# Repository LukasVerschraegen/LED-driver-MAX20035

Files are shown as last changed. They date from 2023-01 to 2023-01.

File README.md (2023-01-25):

# LED-driver-MAX20035
Dit is een schoolproject voor de vakken Industriële toepassing (vermogenelektronica) en Geavanceerd printontwerp.

Enkele video's zijn terug te vinden op mijn youtube kanaal.
https://www.youtube.com/watch?v=1G2xKRNUYQ0&list=PL1lBQKZjCus0v_I9x_oXpihpboHuMBEch




[omschrijving project.pdf](https://github.com/LukasVerschraegen/LED-driver-MAX20035/files/10492971/omschrijving.project.pdf)

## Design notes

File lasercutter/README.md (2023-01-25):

De DXF file is een file dat de lasercutter verstaat om een deksel te maken voor het ontwerp, voor elk materiaal dat u wilt gebruiken zijn er speciefieke instellingen.
Check daarvoor de fabrikant zijn aanradingen en maak dan nodige aanpassingen.

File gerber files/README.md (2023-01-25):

Als u dit ontwerp zelf wilt maken, gaat u naar een fabrikant en dient u deze files in onder de vorm van een 4 layer pcb.

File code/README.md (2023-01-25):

Ik heb een code geschreven voor pwm dimming.
Met de 2de code kan je met je gsm het pwm percentage aanpassen.

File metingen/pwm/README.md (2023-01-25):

Dit is een pwm meting bij 10% pwm, dit varieert constant aangezien we een zwaailicht hebben gemaakt.

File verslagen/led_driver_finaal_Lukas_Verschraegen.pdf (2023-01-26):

Academiejaar: 2022 / 2023

# Led driver project

Verslaggever: | Lukas Verschraegen
Klas: | 3ELO
Lector: | Piet Coussens / Dirk Claus

## Inhoudstafel:

Er zijn ook twee linken die alles in het project omschrijven:
- Er is een link naar een Github pagina, waar elke file ter beschikking is.
- https://github.com/LukasVerschraegen/LED-driver-MAX20035
- Er is een link naar een Youtube pagina waar alle testen te zien zijn.
- https://www.youtube.com/watch?v=1G2xKRNUYQ0&list=PL1lBQKZjCus0v_I9x_oXpi hpboHuMBEch (https://www.youtube.com/watch?v=1G2xKRNUYQ0&list=PL1lBQKZjCus0v_I9x_oXpihpboHuMBEch)

## 1 Waarom kiezen we MAX20053?

We kiezen voor de MAX20053 als buck led drivers en laten deze werken op 12 volt wegens hun bekendheid in de auto-industrie. (voltage autobatterij). https://be.farnell.com/maxim-integrated-products/max20053aud-v/led-driver-aec-q100-sync-buck/dp/2910323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 (https://be.farnell.com/maxim-integrated-products/max20053aud-v/led-driver-aec-q100-sync-buck/dp/2910323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)

## 2 Waarom een synchrone buck convertor gebruiken?

Doorgaans heeft een switch mode power-supply een efficiëntie van 75-85%, dit in tegenstelling tot een synchrone buck convertor die een efficiëntie van 90-95% heeft.

Dit kwam uit deze bron, de website is niet meer actief van “We-online”: https://www.weonline.com/web/en/index.php/show/media/07_electronic_components/news_1/blog/midcom_blog_photos/SMPSChart.pdf (https://www.weonline.com/web/en/index.php/show/media/07_electronic_components/news_1/blog/midcom_blog_photos/SMPSChart.pdf)
Bij de MAX20053 is de efficiëntie duidelijk voorbij de 90%.

Bron: https://www.farnell.com/datasheets/3317033.pdf

## 3 Reden waarom ik een synchrone buck converter gebruik

Bij een asynchrone buck convertor is er bij de schottky diodes een redelijk groot vermogensverlies. Als de stroom door de diode stroomt, zitten we met een voltage drop. Hieruit kunnen we concluderen dat het over een vermogensverlies gaat. Aangezien mosfets schakelen, komen we dit amper tegen.
Het enige nadeel aan de mosfets is dat ze niet tegelijk geschakeld mogen worden, anders heb je een kortgesloten circuit naar de GND.
Voorbeeld uit volgende bron: https://www.digikey.com/Site/Global/Layouts/DownloadPdf.ashx?pdfUrl=F3F58EFCE5E5498A815A2 EF97F4645AA (https://www.digikey.com/Site/Global/Layouts/DownloadPdf.ashx?pdfUrl=F3F58EFCE5E5498A815A2EF97F4645AA)
Here are examples considering these factors:
For these examples, the following parameters will be used:
VIN = 24V
VOUT = 5V
IOUT = 3A
Asynchronous regulator = SC4525A with B340LB Schottky diode Synchronous regulator = SC414

Factor 1 – Duty cycle:
The duty cycle will be the same for both the asynchronous and the synchronous regulators.
Duty cycle = VOUT / VIN = 5V/24V = ~21%
21% of the time the converter is in switching mode while the other 79% is spent in freewheel mode using
the bottom side switch. The power loss for the asynchronous regulator at 3A during freewheel mode is:
VDiode_Drop x (1-Duty cycle) x IOUT = PLoss. = 0.4V x 3A x 79% = 0.95 Watts
The power loss for the synchronous regulator at 3A during freewheel mode is:
VMOSFET_Drop x (1-Duty cycle) x IOUT = PLoss. = 0.1V x 3A x 79%= 0.24 Watts

## 3.1 Conclusie

A.d.h.v. dit voorbeeld zien we duidelijk dat een mosfet beter is. In dit voorbeeld is er 0,24W gebruikt i.p.v. met een diode van 0,95W. Een synchrone buck driver, zorgt er ook voor dat de PCB veel koeler blijft dan een asynchrone buck driver.

## 4 Voor – en nadelen

## Asynchroon

### Voordelen:

- Het is goedkoop.
- Beter als je hogere uitgangsspanning
| gebruikt.

### Nadelen:

- Er is altijd een voltage drop dat vrij groot is
| door diodes.
- Het is minder efficiënt (rond de 85%).

## Synchroon

### Voordelen:

- Mosfet heeft een lage voltage drop omdat het een schakel element is en geen doorlatingselement zoals de diode bij de asynchrone buck convertor.
- Het is een heel efficiënt component (rond de 95%).

### Nadelen:

- Er moet een extra controle circuit zijn zodat de mosfets niet op hetzelfde moment laag zijn (anders is er een kortsluiting)
- Het is een redelijk duur component t.o.v. de asynchrone buck convertor.

## 5 Led specificaties

We gebruiken de CREE LED XPEBBL-L1-0000-00301 wat een blauwe LED is en de rode led van hetzelfde type wat de CREE LED XPEBRD-L1-0000-00501 is.
Omdat ik het principe van een politielicht wilde maken, gebruikte ik leds met vaste kleuren en geen RGB’s.

## Specificaties blauwe led

- Wavelength Typ: 485nm
- Viewing Angle: 135°
- Luminous Flux @ Test: 45.7lm
- Forward Current If Max: 1A
- Forward Current @ Test: 350mA
- Forward Voltage @ Test: 3.1V
- Power Dissipation Pd: 3W

## Specificaties rode led

- Wavelength Typ: 630nm
- Viewing Angle: 130°
- Luminous Flux @ Test: 56.8lm
- Forward Current If Max: 1A
- Forward Current @ Test: 350mA
- Forward Voltage @ Test: 2.2V
- Power Dissipation Pd: 3W

## 6 Blokschema

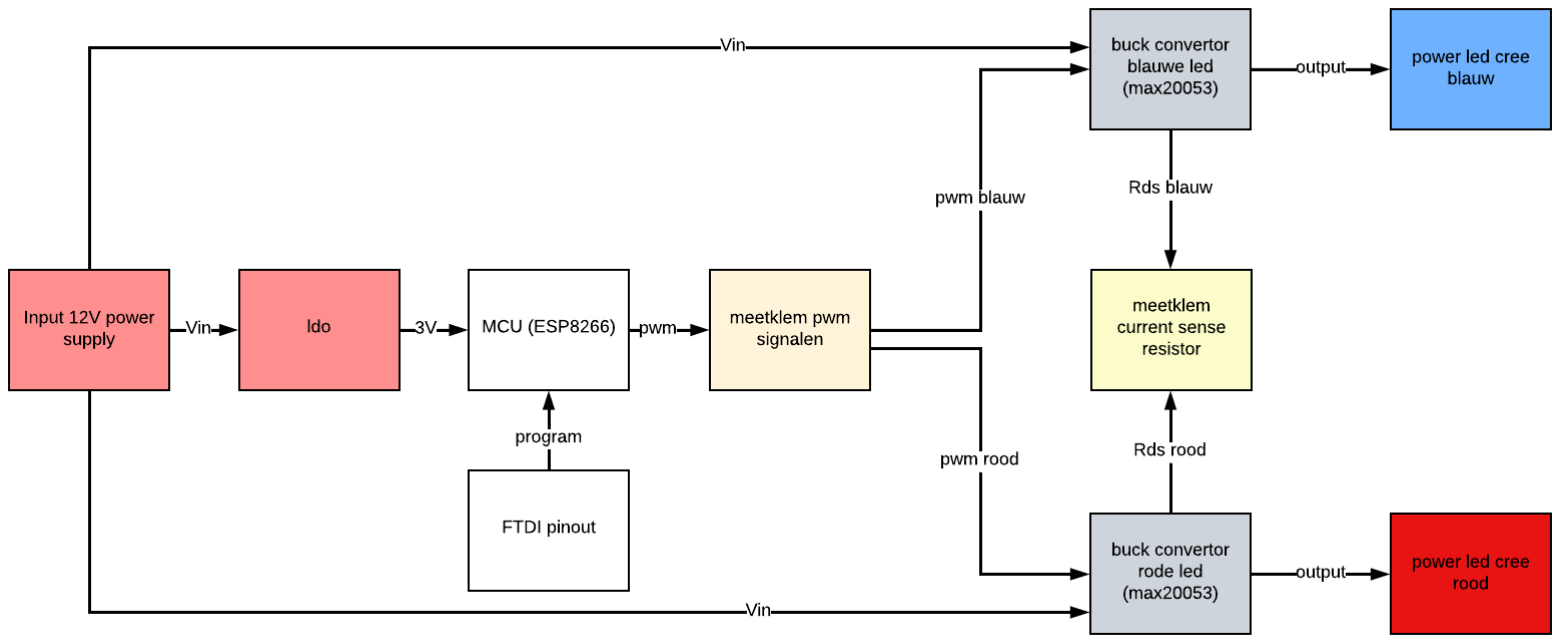
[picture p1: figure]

## 7 Berekeningen van componenten

Startende t.o.v. figuur 3 in de pdf.

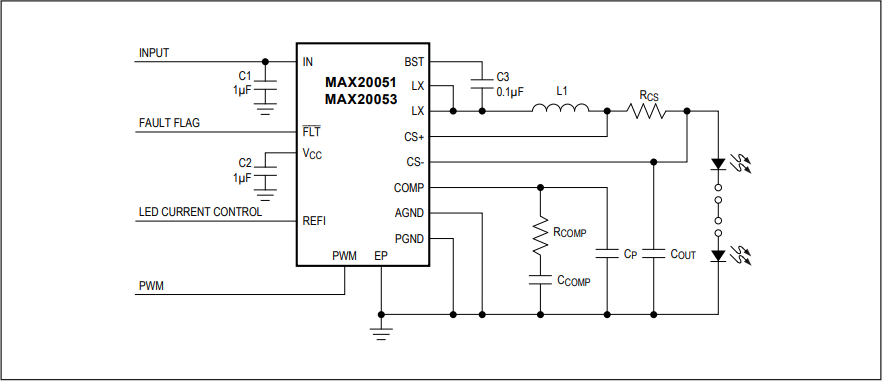
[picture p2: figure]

## 7.1 Rcs

When REFI is set to a voltage >1,3V, the internal reference regulates the voltage across RCS to 220mV. The current is given by:
Iled = | 0.220V Rcs → wat wilt zeggen dat Rcs =

0.220V
Iled

→ Rcs =

0.220V
1A

= 0,220Ω

De stroom door deze weerstand ga ik meten met een oscilloscoop.

## 7.2 Spoel

Selecting a higher switching frequency reduces the inductance requirements, but at the cost of efficiency
The MAX20051/MAX20053 has an external compensation pin for loop stability and this gives more flexibility for output inductor values.
Dit wilt zeggen dat er gekozen mag worden welke inductie gebruikt wordt. Maar om de best passende inductie toe te passen op het systeem neem ik een kijkje bij de MAX20052.
De reden hiervoor is omdat fsw hetzelfde is bij de 20052 als de 20053.
In onze situatie nemen we een spoel van 4.7µH zodat we niet op het minimum van 3.3 µH zitten.

### 7.2.1 Stroomberekening

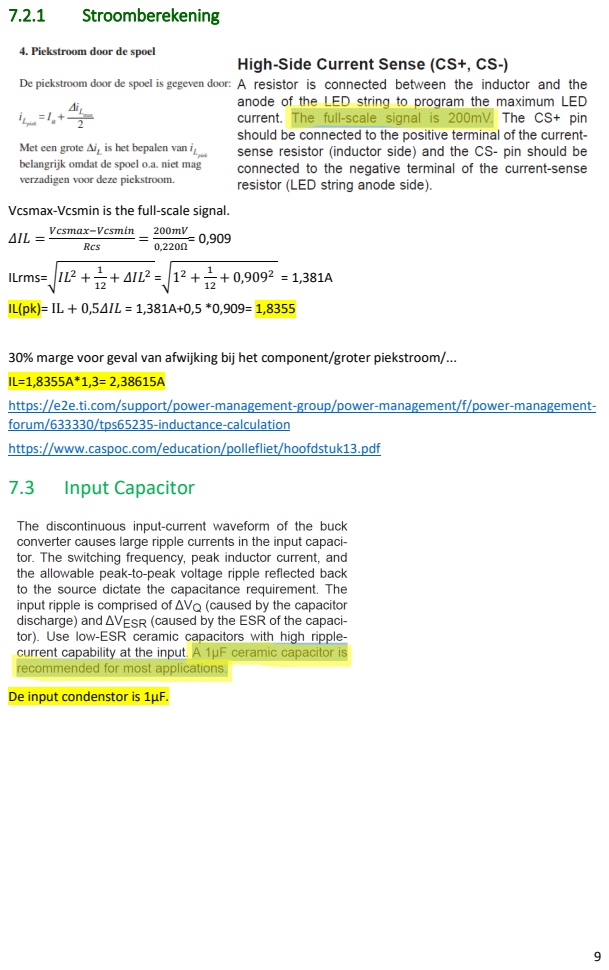
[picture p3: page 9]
ΔIL =; Vcsmax−Vcsmin; Rcs; ILrms=√IL² +; + ΔIL² =√1; Input Capacitor

Vcsmax-Vcsmin is the full-scale signal.

IL(pk)= IL + 0,5ΔIL = 1,381A+0,5 *0,909= 1,8355

30% marge voor geval van afwijking bij het component/groter piekstroom/...
https://e2e.ti.com/support/power-management-group/power-management/f/power-management-
forum/633330/tps65235-inductance-calculation (https://e2e.ti.com/support/power-management-group/power-management/f/power-management-forum/633330/tps65235-inductance-calculation)
https://www.caspoc.com/education/pollefliet/hoofdstuk13.pdf

De input condenstor is 1µF.

## 7.4 Cout

The function of the output capacitor is to reduce the output ripple to acceptable levels. The output capacitance COUT is calculated using the following equation:

where ΔVR is the maximum allowable voltage ripple

We kiezen voor maximum rimpel van 25mV op de output. Vin_min = 11 volt (1 volt marge t.o.v. 12V)
Vin_max = 13 volt (1 volt marge t.o.v. 12V)
Blauwe led:
2 x led → Vled= 3,1V x2 = 6.2V

cout =

((11V−6.2V)∗6.2V)
(25mV∗2∗4,7µH∗13V∗2100kHz²)

= 2,2µF

Rode led:
2 x led → Vled= 2,2V x2 = 4,4V

cout =

((11−4,4V)∗4,4V)
(25mV∗2∗4,7µH∗13V∗2100kHz²)

= 2,155µF

## 7.5 Compensation

Als compensatie netwerk gebruiken we de waarden die ze gebruiken in de Evaluation kit van deze schakeling. Daar heeft de fabrikant al de best passende waarden gekozen voor ons a.d.h.v. testen die zij uitgevoerd hebben. Dit doen we omdat er in de gewone datasheet staat dat het compensatie netwerk moet geoptimaliseerd worden. (zie screenshot: datasheet blz.18)
Dit netwerk dient voor de loop stabilisation.

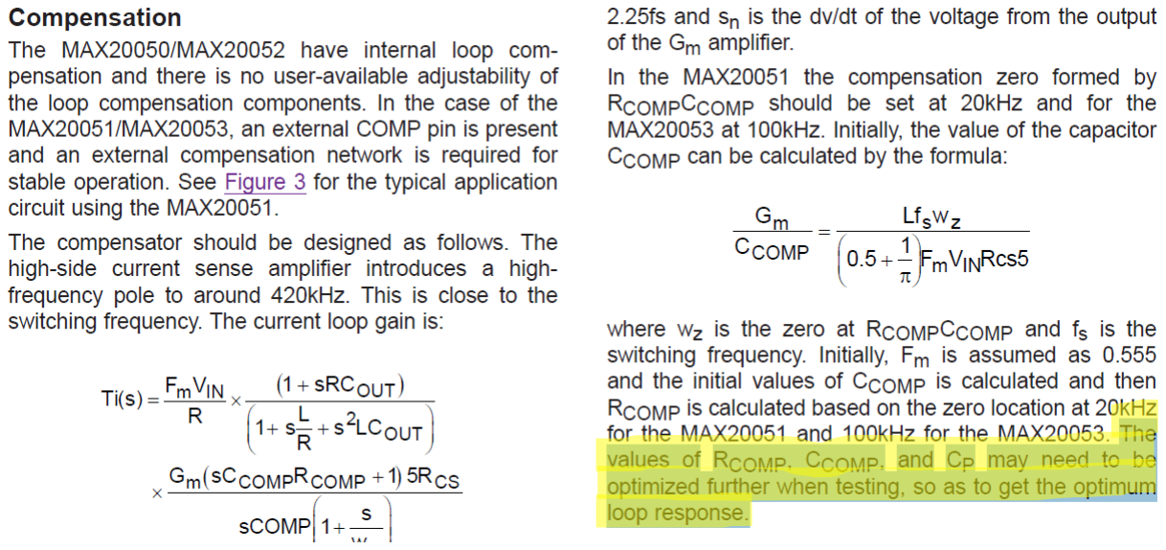
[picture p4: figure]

De waarden die gebruikt worden bij de Evaluation kit zijn: Rcomp= 3,93kΩ en Ccomp=4,7nF (zie screenshot evaluation kit)

## 7.6 FLT

FLT is een active low fault indicator
The FLT pin gaat low wanneer thermal shutdown actief is. Deze pin hangen we dus aan een 10kΩ pull up resistor.

## 7.7 REFI

We zorgen er dus voor dat er een spanning groter dan 1,3V op de REFI pin komt. Hiervoor kunnen we de 3,3V van de LDO gebruiken.

## 7.8 PWM

Hieruit kunnen we afleiden dat we met een ESP8266 de ic met pwm kunnen regelen.
De maximum threshold is 2V, dit halen we zeker aangezien de output van de ESP8266 3,3V oplevert. We kunnen de output ook uitzetten, dan gaat die naar 0V en is deze waarde dus onder de threshold van 800mV.
Dit is een perfecte sturing voor deze schakeling.

## 7.9 EMI

EMI-filters zorgen voor reductie van verstoringen.
We plaatsen zo een filter tussen de cs+ en cs- pin en de Rcs weerstand. Deze filters dienen om elektromagnetische verstoringen te beperken.

## 7.10 Stroommeting

We zorgen ervoor dat we kunnen meten vóór de weerstand en na de weerstand. Deze meting voeren we uit met de oscilloscoop. Zo kunnen we de spanningsval van de weerstand ook duidelijk in beeld brengen.

8 | Verliezen
8.1 | Spoel: Artikelnr. fabrikant:7447789004

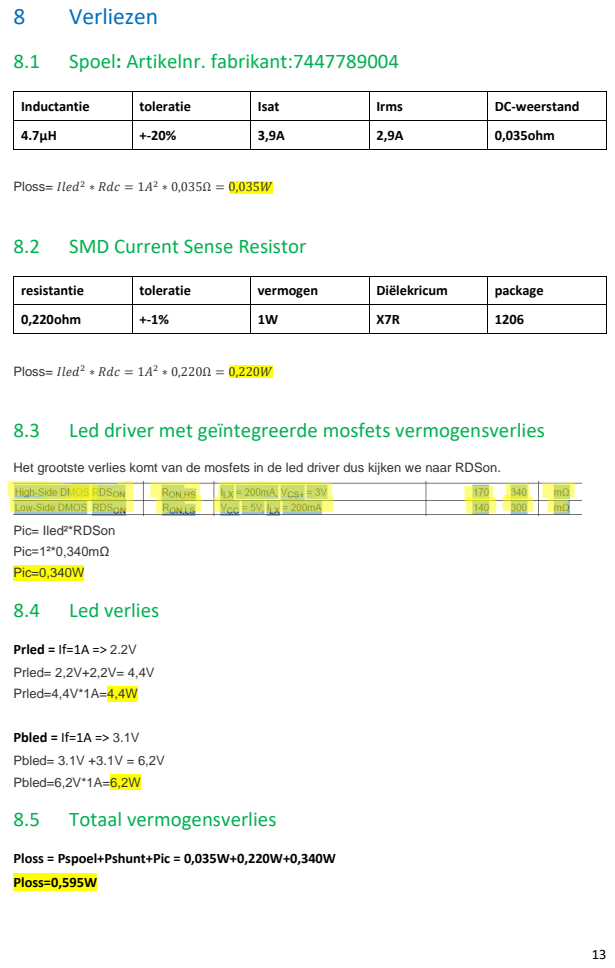
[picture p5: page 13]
Ploss= Iled²; ∗ Rdc = 1A; SMD Current Sense Resistor; Led driver met geïntegreerde mosfets vermogensverlies; Led verlies; Prled = If=1A => 2.2V; Prled= 2,2V+2,2V= 4,4V; Prled=4,4V*1A=4,4W; Pbled = If=1A => 3.1V; Pbled= 3.1V +3.1V = 6,2V; Pbled=6,2V*1A=6,2W; Totaal vermogensverlies

Inductantie | toleratie | Isat | Irms | DC-weerstand

4.7µH | +-20% | 3,9A | 2,9A | 0,035ohm

resistantie | toleratie | vermogen | Diëlekricum | package

0,220ohm | +-1% | 1W | X7R | 1206

Het grootste verlies komt van de mosfets in de led driver dus kijken we naar RDSon.

Pic= Iled²*RDSon
Pic=1²*0,340mΩ
Pic=0,340W

Ploss = Pspoel+Pshunt+Pic = 0,035W+0,220W+0,340W
Ploss=0,595W

## 8.6 Rendement blauwe led

Ptotaal = pled+ploss= 6,2W+ 0,595W Ptotaal = 6,795W

N= pled
ploss =

6,2W
6,795W = 0, 91 → 91%

## 8.7 Rendement rode led

Ptotaal = pled+ploss= 4,4W+ 0,595W Ptotaal = 4,995W

N= pled ploss = | 4,4W 4,995W = 0, 88 → 88%
8.8 | Controle
Vin=12V | 2leds in serie. | I = 1A
Als we dit aflezen komen we aan een efficiëntie van 92% bij een ideaal ontwerp.

## 9 Koelplaat berekeningen

Thermische weerstand van de leds:

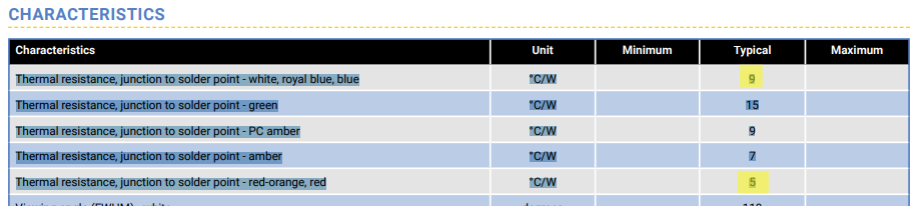
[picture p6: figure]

Via count=10 omdat er 10 via’s het meeste nut hebben voor koeling.
Per via zien we dus een thermische weerstand van 9,3°C/W https://learn.sparkfun.com/tutorials/understanding-thermal-resistance/all

De thermische weerstand van de PCB vond ik niet terug dus staat deze er niet bij en ga ik direct van de via naar de koelplaat. (te verwaarlozen)
Het tussenmateriaal voor de koelplaat aan de pcb te hangen zijn al meegerekend bij de koelplaat aangezien deze standaard met adhesive komt.

## 9.1 Koelvin niet meegerekend ROOD per led

Rj-sp+Rsp-via= 5+9,3=14,3°C/W
2,2W per led met zeker 10 via’s er rond.
2,2W*14,3=31,46°C
Vergeet de ambient temp niet : dus Tj= 31,46°C+25°C= 56,46°C

## 9.2 Koelvin niet meegerekend BLAUW per led

Rj-sp+Rsp-via= 9+9,3=18,3°C/W
3,1W per led met zeker 10 via’s er rond.
3,1W*18,3=56,73°C
Vergeet de ambient temp niet : dus Tj= 56,73°C+25°C= 81,73°C

## 10 Berekeningen opnieuw gemaakt met een koelvin

https://www.tme.eu/be/en/details/icks50x50x50/heatsinks-for-led/fischer-elektronik/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 (https://www.tme.eu/be/en/details/icks50x50x50/heatsinks-for-led/fischer-elektronik/) We zien dat deze koelvin niet specifiek airflow nodig heeft en een thermische weerstand van 4,05°C/W heeft.

## 10.1 Met koelvin rood

2,2W per led met zeker 10 via’s er rond. Tj= 2,2W(5+9,3+4,05)+25°C
Tj=65,37°C

## 10.2 Met koelvin blauw

3,1W per led met zeker 10 via’s er rond. Tj= 3,1W(9+9,3+4,05)+25°C
Tj=94,285°C

## 10.3 Controle met calculator

https://www.daycounter.com/Calculators/Heat-Sink-Temperature-Calculator.phtml

### 10.3.1 Rode led

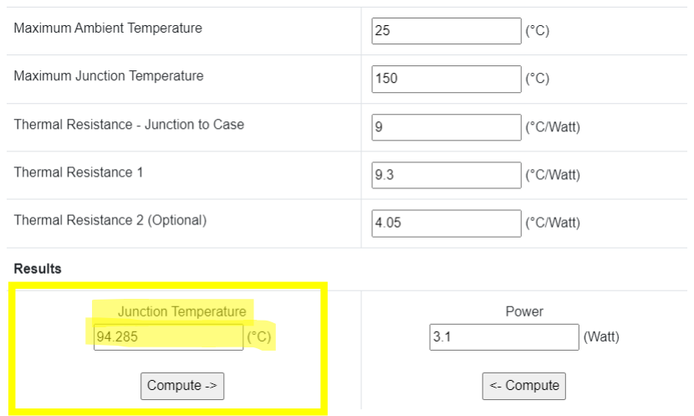
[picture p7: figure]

10.3.2 | Blauwe led
11 | Led matrix
Blauw: 94,285°C | Rood: 65,370°C
Blauw: 94,285°C | Rood: 65,370°C

## 11.1 Conclusie

Wat we berekend hebben klopt dus ook met hetgeen wat de calculator ons weergeeft. Vergeet niet dat een led ook licht geeft dus nemen we 75% van deze temperatuur als licht, zoals aangegeven in de cursus.

### 11.1.1 Rode led

Tj = 65,37°C*0,75 → Temperatuur op de PCB = 49,0275°C

### 11.1.2 Blauwe led

Tj = 94,285°C *0,75 → Temperatuur op de PCB = 70,713°C

## 12 ESP8266

Enkele opmerkingen bij het ontwerpen van de ESP8266 schakeling.
Opmerking nr. 1: Plaats een condensator voor en na de LDO, deze zorgen voor een buffer netwerk. Een buffer netwerk dient om de rimpelstroom te verkleinen.

Opmerking nr. 2: Plaats een 100nF over de knop. Ten eerste is dit interessant voor de debounce weg te werken, en ten 2de is dit interessant voor de power on reset.

https://www.techtarget.com/whatis/definition/power-on-reset-PoR#:~:text=A%20power%2Don%20reset%20(PoR,that%20it%20is%20powered%20up. (https://www.techtarget.com/whatis/definition/power-on-reset-PoR)
Een power-on reset (PoR) is een schakeling die een voorspelbare, geregelde spanning levert aan de ESP8266 bij de eerste inschakeling van stroom. PoR zorgt ervoor dat de microcontroller elke keer dat hij wordt ingeschakeld in dezelfde toestand start.

Opmerking nr. 3: Er mogen geen signalen lopen onder de antenne van de ESP8266 dit is om rekening te houden met het ontwerpen van de pcb.

Opmerking nr. 4: Volgens deze website kan de ESP8266 stroompieken hebben van 450mA dus een LDO die een paar 1,2 ampère aankan is meer dan genoeg. (LDO: LDL1117). https://www.tweaking4all.nl/hardware/esp8266/beginnen-met-esp8266/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,een%20oude%20telefoon%2 0voor%20gebruiken. (https://www.tweaking4all.nl/hardware/esp8266/beginnen-met-esp8266/)

Belangrijke pinnen:
https://www.youtube.com/watch?v=L4S9XelSvhI&t=115s VCC: Power 3.0 ~ 3.6V
GND: Ground
RESET: External reset signal (Low voltage level: Active)
CH_PD: Chip Enable. High: On, the chip works properly; Low: Off, a small current
GPIO0: (FLASH) I/O General purpose IO, If low while reset/power on takes chip into serial programming mode
GPIO1: (TX)I/O General purpose IO and Serial TXd
GPIO3: (RX)I/O General purpose IO and Serial RXd
GPIO2: I/O General purpose IO and Serial1 TXd

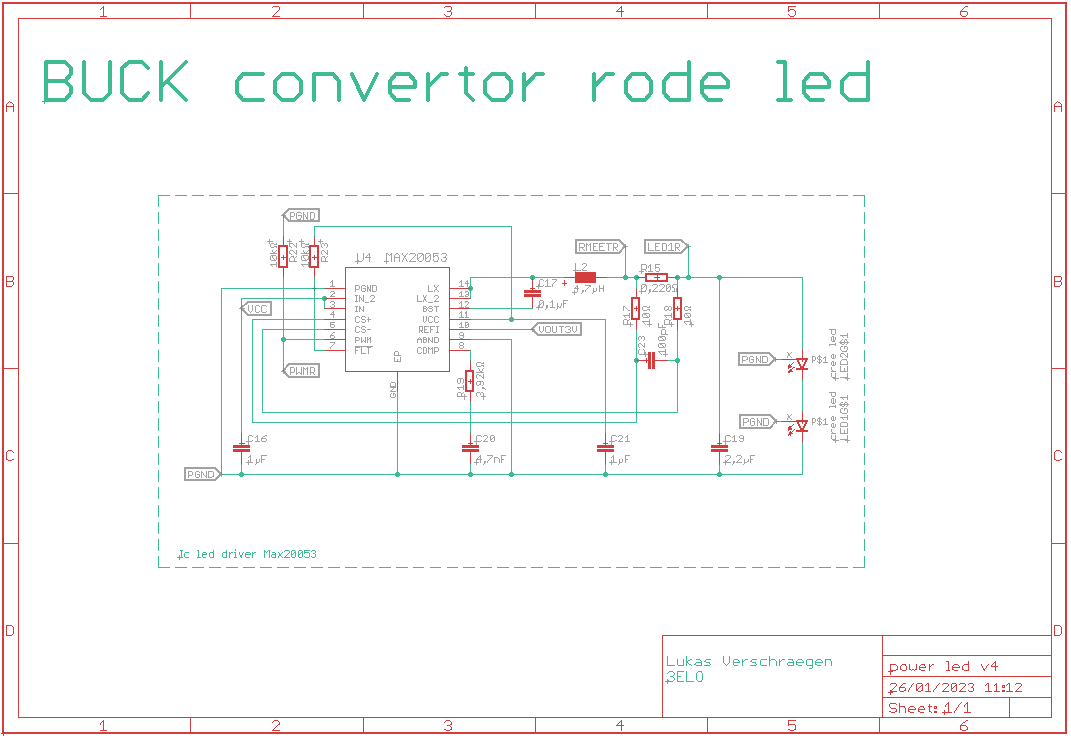
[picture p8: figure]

## 13 PCB design

## 13.1 Via’s

Als we via’s onder de pad plaatsen, dan krijg ik steeds errors. Dit is niet ideaal aangezien er ook een soldeersel onder de pad moet komen. Als we dit in de oven steken, dan drupt het soldeersel door de via’s. Daarom kiezen we via’s die de grote hebben van 0,3mm, door deze soort te gebruiken hebben we dit effect niet. We kunnen de error’s dus approven.

De via’s die het dichtste bij de led staan hebben het meeste effect om te koelen. Daarom hebben we bij de koelberekeningen gewerkt met 10 via’s per led.

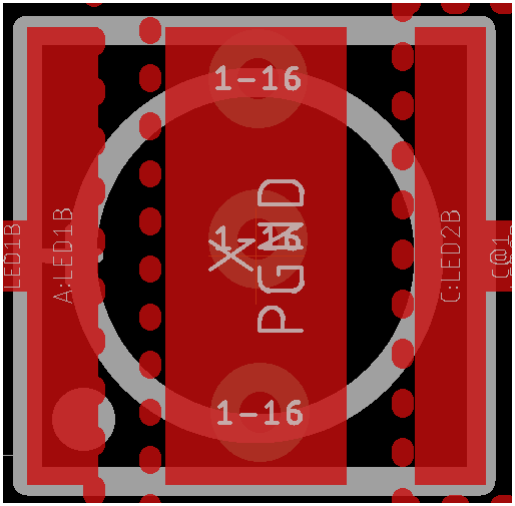
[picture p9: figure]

## 13.2 Kelvin connection’s

Een kelvin connectie wordt gebruikt om een stroommeting te maken. Deze meting dient voor de feedback naar de led driver. Om de stroom zelf te meten gaan we een scope gebruiken.
Zoals te zien is, hebben we een hoog stroompad, hierop kunnen we dus niet meten.
Daarom trekken we 2 kleine draden van de weerstand naar de meetklemmen, dit vormt een laag stroompad en is dus wel meetbaar.

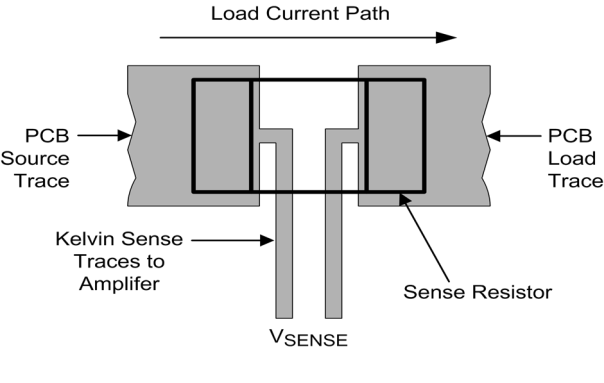
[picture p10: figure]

https://alpelectronics.se/en/what-is-a-kelvin-connection-and-a-shunt-resistor/

## 13.3 Exposed section voor de koelvin op te monteren

Als we de silkscreen weg etsen dan hebben we koper dat zichtbaar is en zo zal de temperatuur beter geleiden.
https://electronics.stackexchange.com/questions/447331/how-to-remove-solder-mask-in-eagle
Bijvoorbeeld: | uitgewerkt op eigen pcb:

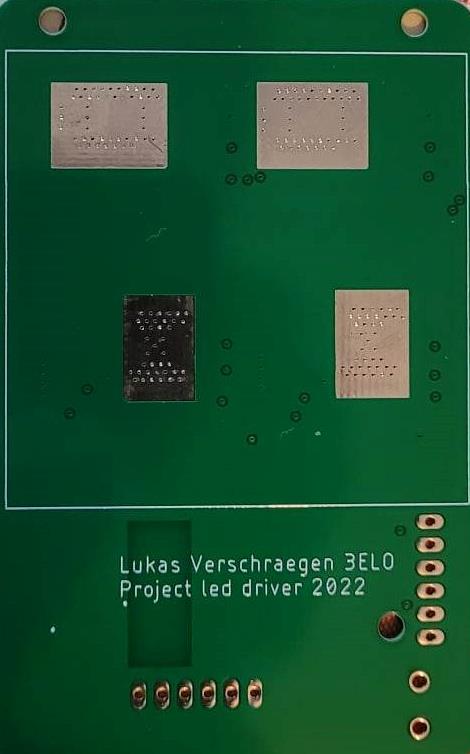
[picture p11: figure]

## 13.4 Dikte van de PCB

https://cart.jlcpcb.com/impedance?_ga=2.35895136.1315427483.1592868937-1547839306.1592059153 (https://cart.jlcpcb.com/impedance?_ga=2.35895136.1315427483.1592868937-1547839306.1592059153)

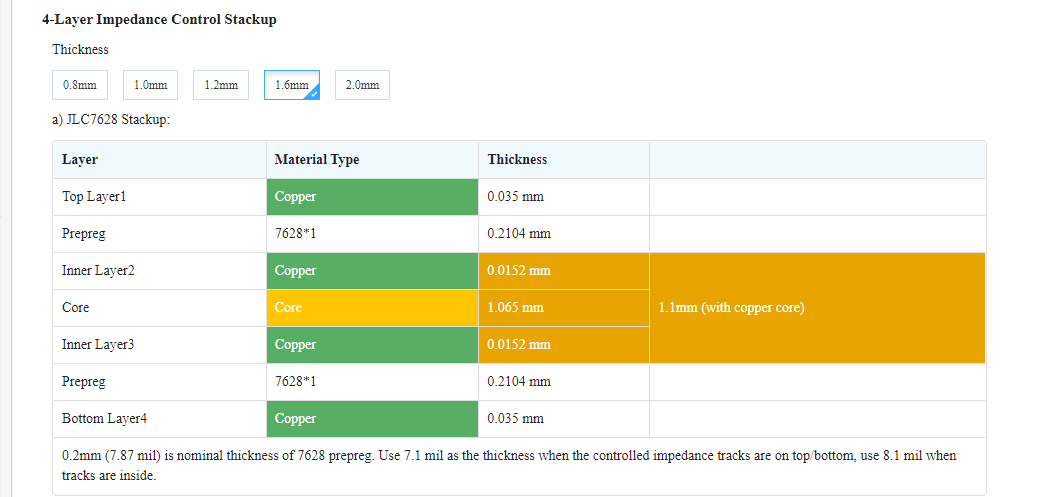
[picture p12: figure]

## 13.5 Legende van de gemaakte lagen

Dit is de toplaag met links silkscreen en polygon en rechts de toplaag met silkscreen zonder polygon. (nr. 1 in de legende)

Dit is de top laag zonder silkscreen.

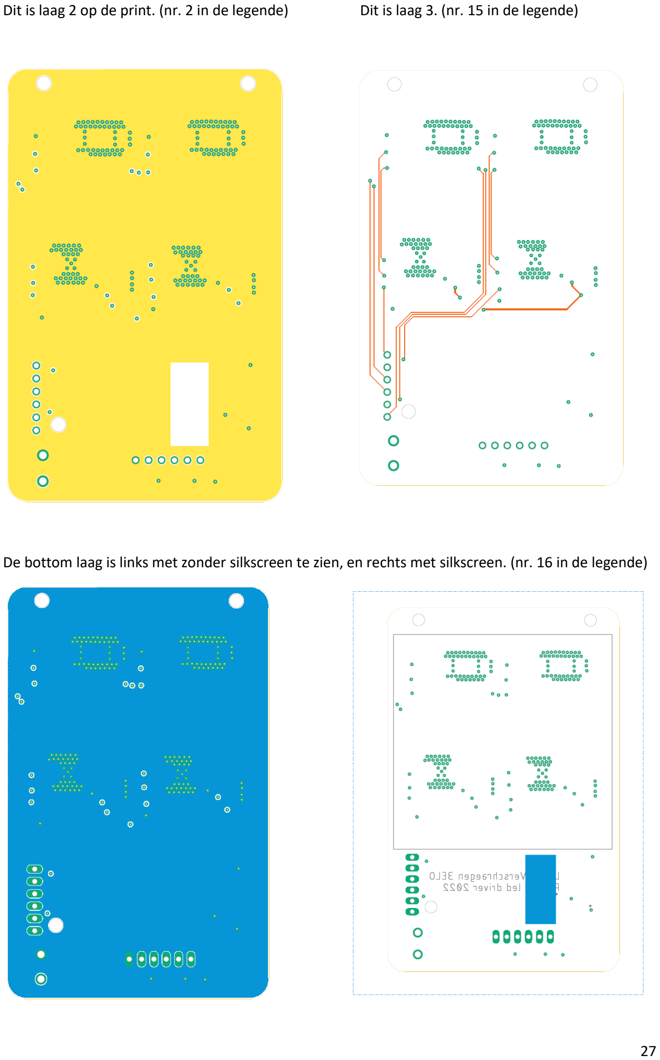
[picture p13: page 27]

Dit is laag 2 op de print. (nr. 2 in de legende) | Dit is laag 3. (nr. 15 in de legende)

De bottom laag is links met zonder silkscreen te zien, en rechts met silkscreen. (nr. 16 in de legende)

Hieronder ziet u de totale print met alle lagen samen.

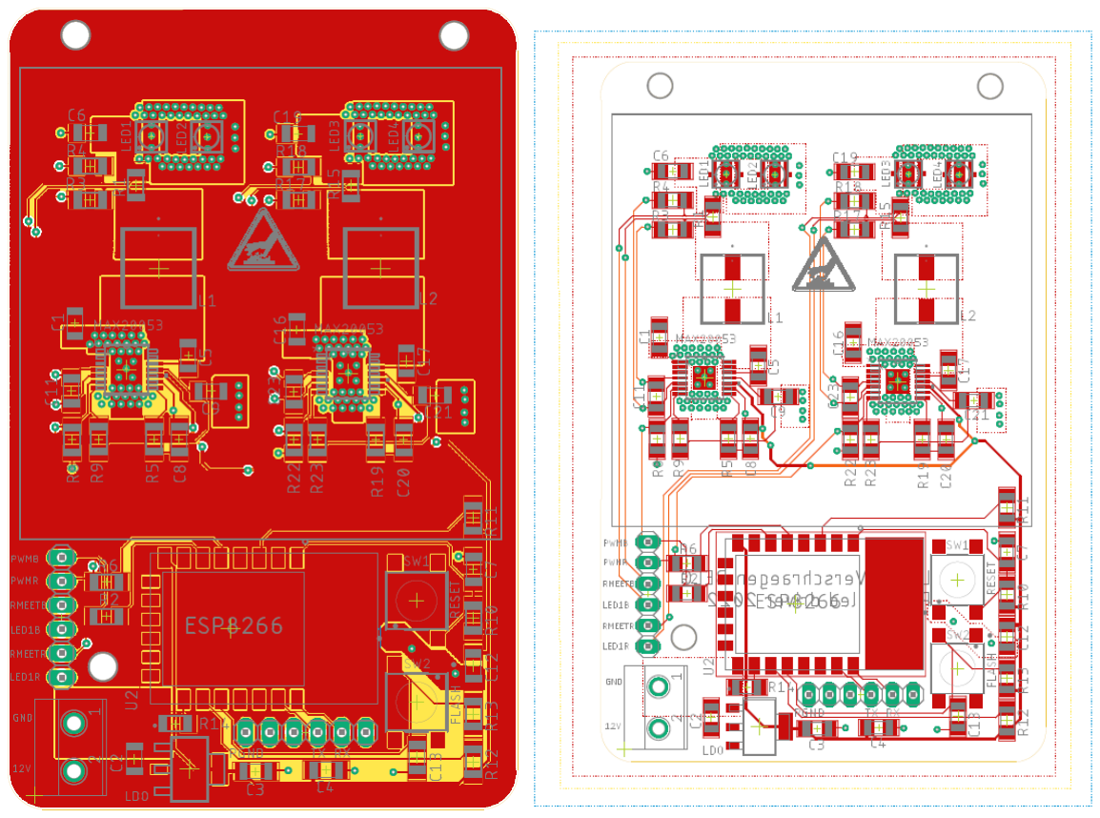
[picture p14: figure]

## 13.6 Foto’s van de pcb na productie

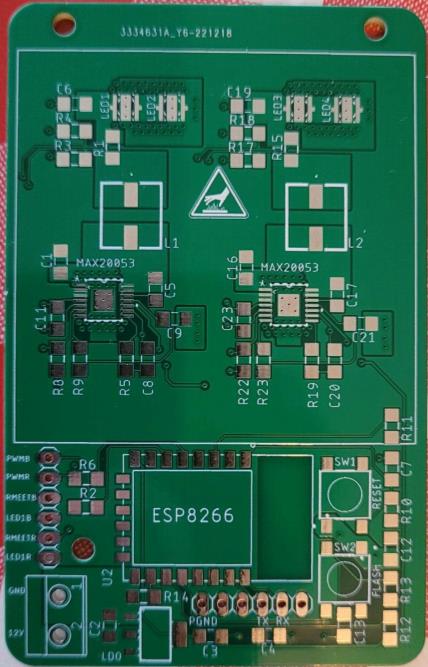
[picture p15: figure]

Bottom side: | Top side:

13.7 Foto’s van de pcb na bestukking.

Voor het reflow process: | na het reflow process:

### 13.7.1 Het reflow process

Voor het reflow process heb ik me gebaseerd op de meest gevoelige componenten. Wat de leds en de spoel zijn.
Daar vinden we enkele curves van terug in de datasheets:
Datasheet leds: | Datasheet spoel:

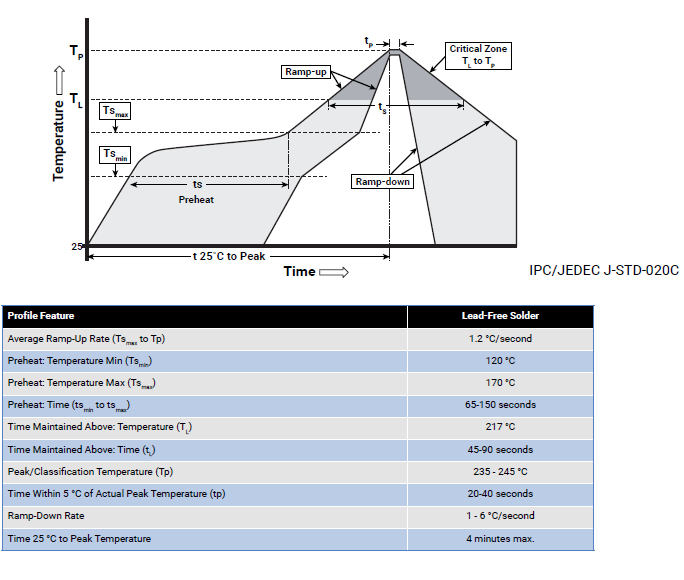
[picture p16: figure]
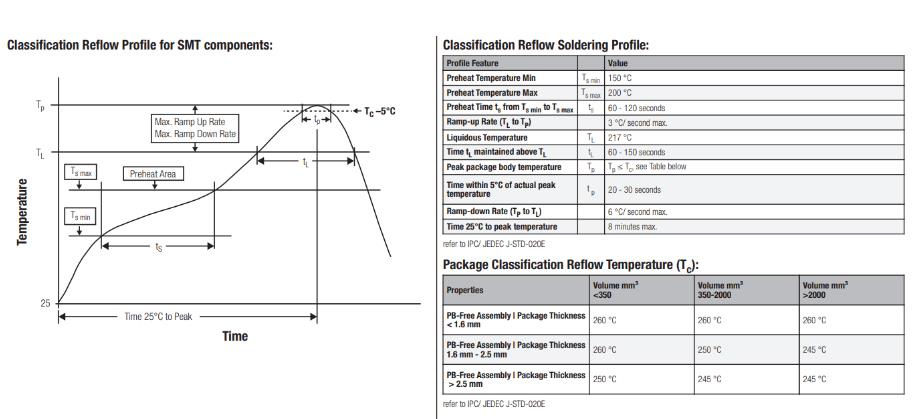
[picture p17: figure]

Hier zien we enkel de curves voor loodvrij solderen. In het labo hebben we soldeersel gebruikt dat loodhoudend was. D.w.z. dat de temperaturen over het algemeen 20 graden lager liggen dan bij loodvrij solderen.

De curve die we gemaakt hebben komt ongeveer overeen met de curve uit de datasheets. Voor de veiligheid laten we de lade opengaan bij een iets lagere temperatuur dan bij piektemperatuur.

We zien hier het verloop en gaan eerst langzaam naar 150°C en gaan dan iets sneller naar een maximale van 220°C en behouden we deze voor 20 seconden. Dit is het minimale van wat beide datasheets aanraden. Eens de deur open is op een temperatuur van 170°C gaat het snel naar beneden om zo veilig mogelijk te werk te gaan.

We kunnen het live verloop volgen van de temperatuur door de ntc aan het grootste oppervlakte van een pcb te hangen.

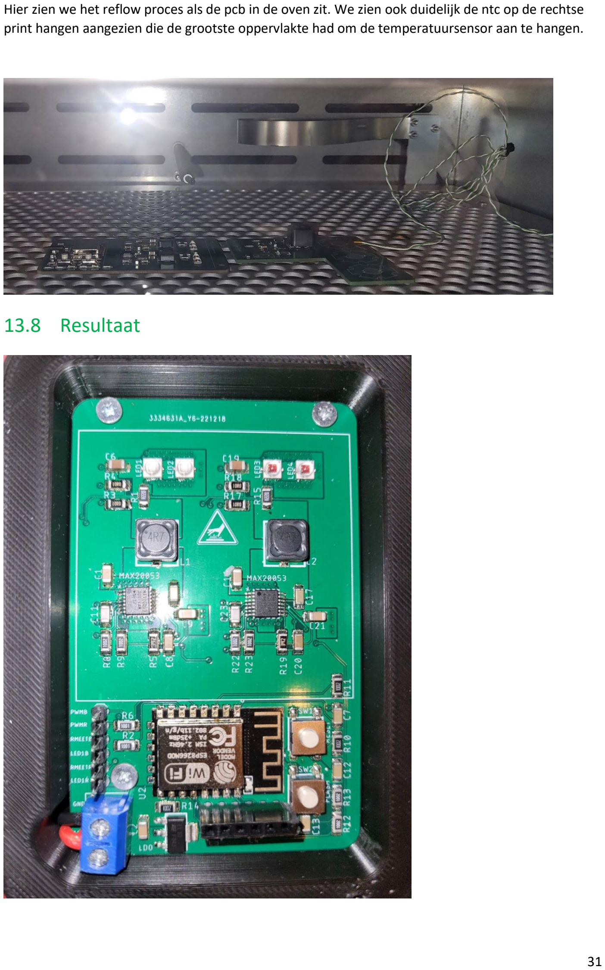
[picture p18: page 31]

Hier zien we het reflow proces als de pcb in de oven zit. We zien ook duidelijk de ntc op de rechtse print hangen aangezien die de grootste oppervlakte had om de temperatuursensor aan te hangen.

## 13.8 Resultaat

## 14 Metingen

## 14.1 De wet van ohm om de stroommeetweerstand te berekenen

14.1.1 | Stroommeting van de rode led
I= U Rsense | → max(1)−max(2)
| 0,220 =
| 1
| 0,220 = 4,5A

Conclusie ➔ Ik kan concluderen dat de stroommeting niet oké is, ik heb waarschijnlijk niet genoeg ingezoomd op de tijdsbasis om de getallen na de komma te zien. Dit kan er voor zorgen dat de waarde van de stroom wel correct waren.

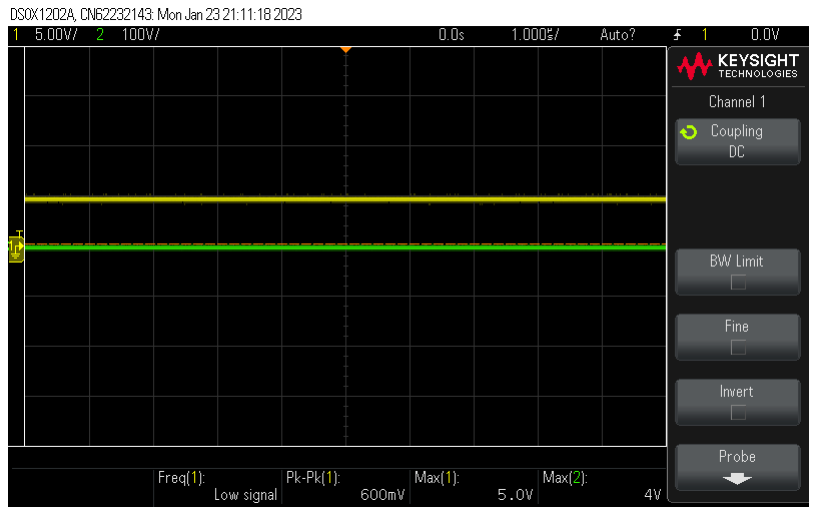
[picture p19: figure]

### 14.1.2 Stroommeting blauwe led

I= U
Rsense

→

| max(1)−max(2)
| 0,220 =
| 1
| 0,220 = 4,5A

Conclusie➔ Ik kan concluderen dat de stroommeting niet oké is, ik heb waarschijnlijk niet genoeg ingezoomd op de tijdsbasis om de getallen na de komma te zien. Dit kan er voor zorgen dat de waarde van de stroom wel correct waren.

## 14.2 Vaststelling pwm pulsen

Aangezien het een pwm signaal is dat afwisselt, zien we dat als de rode led stijgt, de blauwe daalt. Dit is een screenshot op een bepaald moment want de signalen variëren constant van 0 naar 100%. Pwm blauwe led. Op 10%.

Pwm rode led. Op 10%

## 15 Warmtemetingen

## 15.1 Fenomeen van IR straling

Met het fenomeen van IR straling, bedoel ik dat er een rode led aanwezig is op de pcb. Uit deze rode led komt er ook infrarood licht en dit heeft invloed op de temperatuur van de camera. Het verschil bedraagt ongeveer 20°C. (We zien duidelijk de distorsie op de warmtecamera.)

Als het systeem in de stekker zit, geeft de camera tussen de 86 en 93 graden weer. Zie hierboven screenshot 1.

(ongeveer dus 90°C)

Wanneer we de stekker uittrekken, krijgen we ongeveer 20 graden verschil. (Dit komt dan neer op ongeveer de 70-73°C) voor het warmste punt op de pcb.

We kunnen dus vaststellen dat ons berekende temperaturen ongeveer correct zijn. Enkel als de stekker uit is dalen de temperaturen snel. We kunnen enkel de 70-73°C visueel vaststellen, aangezien dit moeilijk is om op foto vast te leggen. (Hiervoor zijn we niet snel genoeg.)

Systeem met de voeding actief.

Systeem met de voeding uitgeschakeld .

De ldo wordt ook warm, maar wordt beperkt warm tot 53 °C | Systeem met de voeding actief.
De koelvin functioneert ook goed, maar zou beter functioneren als die anders staat zodat de warme lucht weg kan. (dit is een thermische foto niet bij vol vermogen getrokken) | Systeem met de voeding actief.

## 16 BOM

Deze bill of materials is berekend zonder verzendingskosten. Bij de PCB is de stencil wel meegerekend.
ALLE PORDUCTEN zijn ROHS compliant.
Bij de microcontroller kan je heel veel besparen op AliExpress, vandaar dat dit alternatief ook op de lijst staat. (Dit is een duur component.)

## 17 3D ontwerp

Het ontwerpen van een 3D print heb ik gedaan met fusion360 aangezien ik daar mijn printplaat kon importeren als 3D ontwerp (zie de 3de foto). Hier rond hebben we de behuizing ontworpen en een open ruimte opengehouden om de kabels te laten lopen naar de pcb d/ DC jack te laten passen en de print te voorzien van verluchtingsgaten voor het koelelement te koelen. https://www.youtube.com/watch?v=5hComh1hFzY&t=1435s

De koeling en dc jack is te zien op de foto | Op deze screenshot zien we links de sleuf voor de kabels.

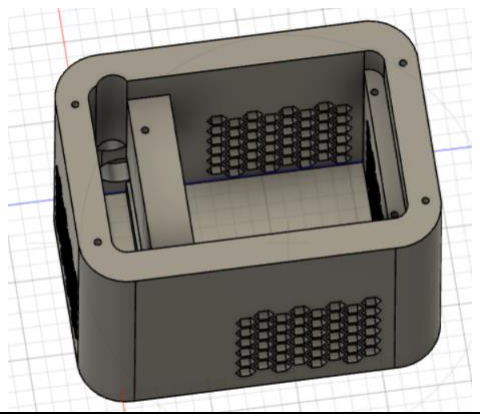
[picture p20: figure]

Op deze foto zien we de pcb als 3D ontwerp: | De opstart van de print:

Hier zien we de complete behuizing:

## 18 Laser cutter

## 18.1 Design uploaden

Onderstaande file is de dxf file. Dit laden we in, in de software van de lasercutter zelf.

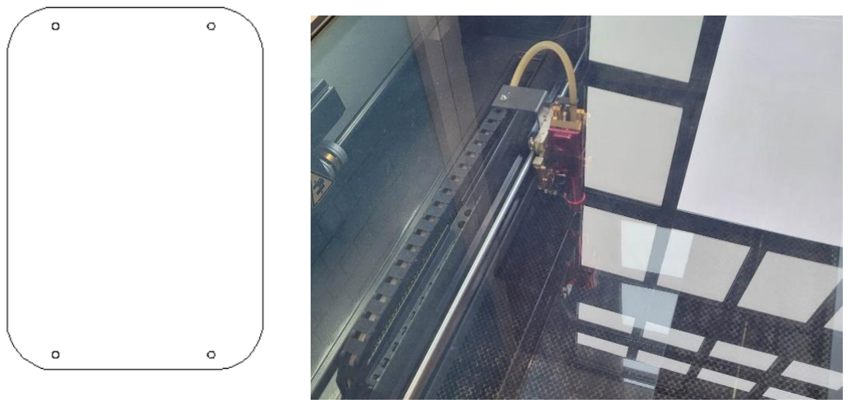
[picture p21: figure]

Het ontwerp uploaden in de software voor de lasercutter (LaserWorksV6).

De power van de laser is 100 Watt en de schaal in de software staat op 100%. Als we kijken in de cursus voor Acrylic te snijden, komen we op power van 85% terecht wat overeenkomt met 85Watt.

De snelheid van de laser moet op 30mm/s staan. Al snel werd duidelijk dat we niet door dit materiaal konden laseren. Na een paar testen zijn we gezakt naar een snelheid van 15 mm/s (Dit was trial en error, elk materiaal is verschillend ook al heeft het een gelijkaardige dikte t.o.v. vorige testen met de lasercutter.)

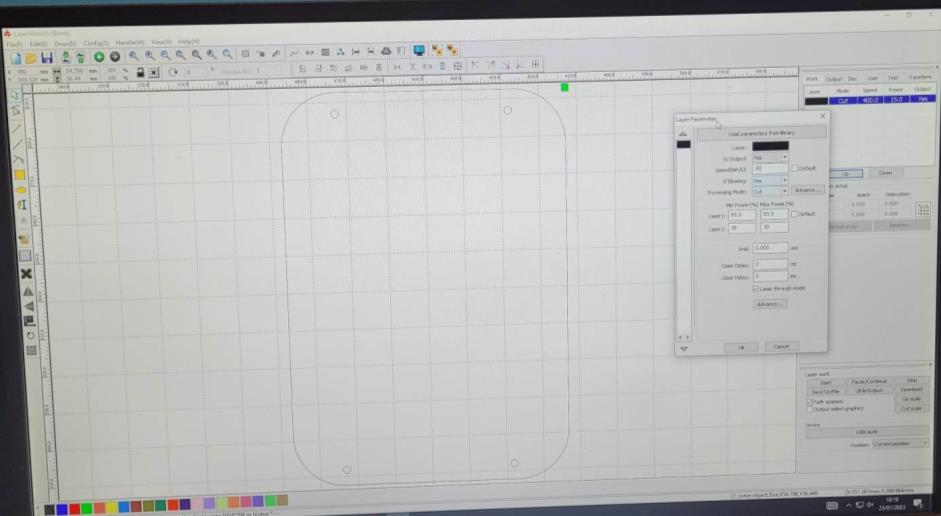
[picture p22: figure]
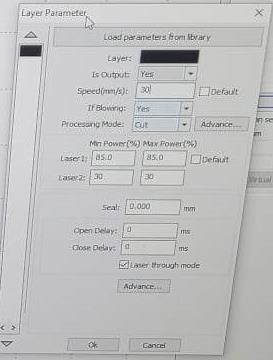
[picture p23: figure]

## 18.2 Eind resultaat

Gekleurde acrylic en doorzichtige acrylic om te testen wat het beste is. Dit is puur eigen voorkeur, maar technisch gezien is het gekleurd acrylic beter om het licht te diffusen.

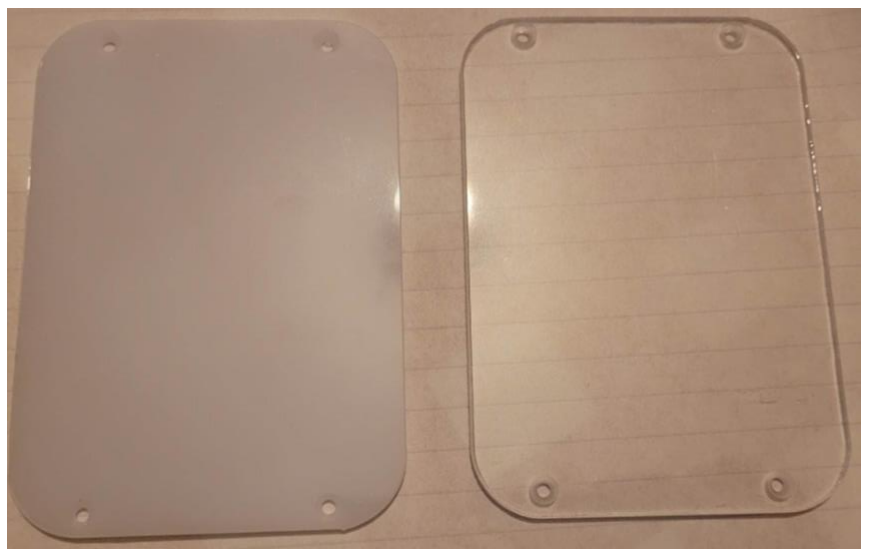
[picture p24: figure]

Het resultaat past mooi op de behuizing, en is veilig om aan te raken zonder scherpe kanten door een ontbramer te gebruiken. De schroefkoppen heb ik mooi verzonken in het acrylic.

In werking wordt het licht mooi gediffused.

## 19 Code

Di is een simpele code voor een zwaailicht te maken: de geavanceerde code met website is terug te vinden op de Github pagina.

int led_pinR = 14;
int led_pinB = 12;
void setup() {
//Declaring LED pin as output pinMode(led_pinR, OUTPUT); pinMode(led_pinB, OUTPUT); Serial.begin(9600);
}

void loop() {; //analogWrite(led_pinB, 1023);; for(int i=0; i<=1023; i=i+3) {; delay(1);; } for(int i=1023; i>=0; i=i-3) {

//analogWrite(led_pinR, 1023); //leds constant op vol vermogen

analogWrite(led_pinR, i); // fade in first LED analogWrite(led_pinB, 1023-i); // fade out second LED

analogWrite(led_pinR, i); // fade out first LED analogWrite(led_pinB, 1023-i); // fade in second LED

## 20 Besluit

## 20.1 Algemene test volgorde

- Eerst testen van het esp deel door extern op te starten en een simpel blink programma te runnen.
- Als dit lukt, pwm sturen en meten op een pin die niet aangesloten zit op de led drivers zelf. Zo weten we dat pwm lukt met de esp.
- Dan sturen we de led driver aan. Als pwm = 0 gaan de leds niet branden, en als pwm groter is dan 0 dan pas zullen de leds oplichten.
- Als er fouten zijn, debuggen.
- Meet op de pwm pinnen van de led driver de signalen nog eens na.
- Meet over de stoommeetweerstand of je daar iets meet.
- Bij extra fouten meer debuggen, dit zijn de stappen die ik ondernam en het werkte direct.

## 20.2 Algemene besluiten

Na testen heb ik kunnen concluderen dat mijn PCB volledig werkt.
Onder andere:
- De werkingstemperaturen zijn zoals verwacht als je de rekening houdt met de ir compensatie.
- De driver werkt zoals verwacht, als ik geen pwm heb, geven de leds geen licht.
- De ESP8266 dat gemonteerd is op de pcb werkt volgens verwachtingen.
Om te uploaden druk je reset in, dan flash, dan laat je reset eerst los en dan flash.
Dit werkt correct.
- De pwm signalen hebben het verwachte effect. Dit effect is dat ze constant op en neer gaan op de scope omdat ik een fading gebruik.
- Alles paste mooi in de behuizing en er is rekening gehouden met de koelvin, zodat de koelvin juist georiënteerd kan worden om voldoende te koelen.

## 20.3 Werkpunten

Enkele werkpunten zijn:
- Een koelvin die zwart is zal een betere thermische geleiding hebben en een stuk kleiner zijn.
- Metingen beter bekijken, en niet vergeten om ver genoeg in te zoomen op de scope.
- Plaats de ldo beter langs de kant van de koelvin omdat deze dan mee kan koelen. (Deze is nu opgesplitst in een kant voor de led driver en een kant voor de esp om overzicht te bewaren.)
- Plaats een ldo van 3,3 volt voor de esp i.p.v. een 3 volt ldo. (3 volt werkt ook, maar een 3,3 volt ldo heeft toch iets meer marge.)
- Voorzie eventueel nog een extra grondklem om de gnd van de scope probe aan te hangen, deze moest nu elke keer aan de voedingskant bevestigd worden en dus was dit vaak minder praktisch.
- Om een eenvoudiger en meer kost efficiënter project te maken, zou ik gebruik maken van mosfets, dit was te laat om te implementeren aangezien de print al opgestuurd was naar de fabrikant.

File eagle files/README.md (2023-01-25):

Hier vindt u de files om aanpassingen te maken of voor alles in detail te bekijken.
In de submap, vindt u zowel elke laag apart in pdf als de schema's in pdf vorm.

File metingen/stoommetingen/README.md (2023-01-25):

De metingen zijn niet correct let op!!! Dit was een testfase waarbij de tijdsbasis op de scope niet klein genoeg stond.

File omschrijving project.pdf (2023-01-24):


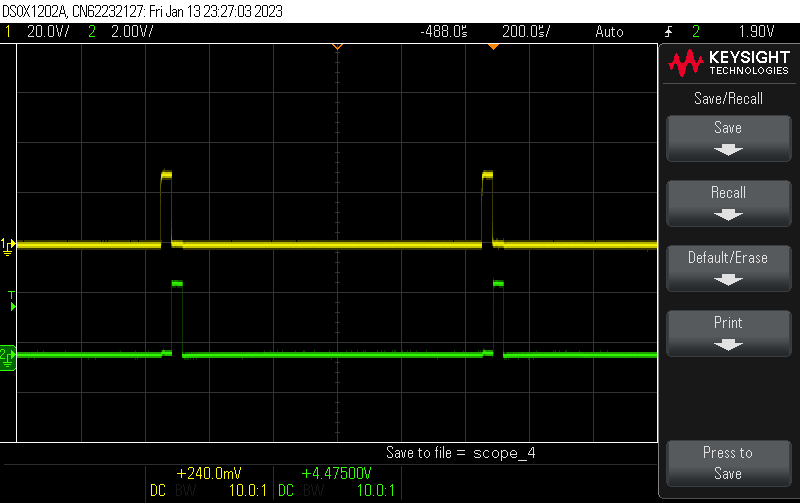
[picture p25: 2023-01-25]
metingen/pwm/rode led pwm.png

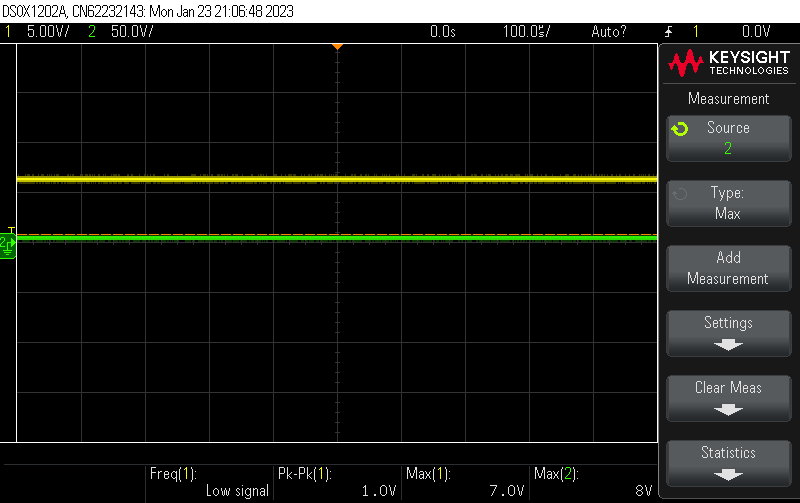
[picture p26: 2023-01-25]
metingen/stoommetingen/stroommeting blauwe led.png

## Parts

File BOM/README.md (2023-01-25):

BOM staat voor bill of materials, met andere woorden, wat 1 print zou kosten.

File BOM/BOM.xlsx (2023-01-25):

componenten | package | ROHS | leverancier | link | aantal | prijs | totaalprijs | alternatief | prijs
MAX20053 | TSSOP | ok | farnell | https://be.farnell.com/maxim-integrated-products/max20053aud-v/led-driver-aec-q100-sync-buck/dp/2910323 | 2 | 2.58 | 5.16
cree led rood | Cree® XLamp® XP-E2 LEDs rood | ok | farnell | https://be.farnell.com/cree/xpebrd-l1-0000-00501/led-hb-red-3w-56-8lm/dp/2839924 | 2 | 1.14 | 2.28
cree led blauw | Cree® XLamp® XP-E2 LEDs blauw | ok | farnell | https://be.farnell.com/cree/xpebbl-l1-0000-00301/led-hb-blue-3w-45-7lm/dp/2839921 | 2 | 2.04 | 4.08
ldo | LDL1117S30R | ok | farnell | https://be.farnell.com/stmicroelectronics/ldl1117s30r/ldo-fixed-3v-1-2a-sot-223-4/dp/2778101 | 1 | 1.16 | 1.16
esp8266 | ESP8266-12E | ok | opencircuit | https://opencircuit.be/product/esp8266-esp-12e-wifi-module | 1 | 4.85 | 4.85 | https://nl.aliexpress.com/item/1005001520382593.html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 | 1.48
knoppen | B3FS-1012 | ok | farnell | https://be.farnell.com/omron/b3fs-1012/tactile-switch-0-05a-24vdc-illum/dp/1181017?ost=b3fs-1012 | 2 | 0.893 | 1.786
pin header 6 pinnen | 1x06 | ok | farnell | https://be.farnell.com/amp-te-connectivity/826926-6/header-straight-6way/dp/1248144 | 2 | 0.478 | 0.956
terminal block 5mm | 5mm | ok | farnell | https://be.farnell.com/camdenboss/ctb1202-2bk/terminal-block-wire-to-brd-2pos/dp/1716993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 | 1 | 0.293 | 0.293
spoel 4,7µH | afmetingen afhankelijk van grootte | ok | farnell | https://be.farnell.com/wurth-elektronik/7447789004/choke-4-7uh-smd/dp/1635969 | 2 | 2 | 4
condensator 4,7µF | 1206 smd | ok | farnell | https://be.farnell.com/kemet/c1206c475k3ractu/cap-4-7-f-25v-10-x7r-1206/dp/1288211 | 1 | 0.786 | 0.786
condensator 4,7nF | 1206 smd | ok | farnell | https://be.farnell.com/kemet/c1206c472k5ractu/cap-4700pf-50v-10-x7r-1206/dp/1414738 | 2 | 0.107 | 0.214
condensator 2,2µF | 1206 smd | ok | farnell | https://be.farnell.com/avx/12061c225kat2a/cap-2-2-f-100v-10-x7r-1206/dp/2043047 | 2 | 0.368 | 0.736
condensator 1µF | 1206 smd | ok | farnell | https://be.farnell.com/avx/12065c105kat2a/cap-1-f-50v-10-x7r-1206/dp/1301811 | 6 | 0.175 | 1.05
condensator 100pF | 1206 smd | ok | farnell | https://be.farnell.com/multicomp/mc1206n101j500ct/cap-100pf-50v-5-c0g-np0-1206/dp/1759327 | 2 | 0.121 | 0.242
condensator 0,1µF | 1206 smd | ok | farnell | https://be.farnell.com/avx/12065c104kat2a/cap-0-1-f-50v-10-x7r-1206/dp/499389 | 5 | 0.073 | 0.365
weerstand 0,220Ω | 1206 smd | ok | digikey | https://www.digikey.be/nl/products/detail/ohmite/KDV12FR220ET/10476492 | 2 | 0.3 | 0.6
weerstand 10kΩ | 1206 smd | ok | farnell | https://be.farnell.com/bourns/cr1206-fx-1002elf/res-10k-1-0-25w-1206-thick-film/dp/2008395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 | 9 | 0.0467 | 0.4203
weerstand 10Ω | 1206 smd | ok | farnell | https://be.farnell.com/vishay/crcw120610r0fkeahp/res-10r-1-0-75w-1206-thick-film/dp/1738986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 | 4 | 0.263 | 1.052
weerstand 1kΩ | 1206 smd | ok | farnell | https://be.farnell.com/multicomp/mcwr12x1001ftl/res-1k-1-0-25w-1206-thick-film/dp/2447473 | 2 | 0.0138 | 0.0276
weerstand 3,92kΩ | 1206 smd | ok | farnell | https://be.farnell.com/bourns/cr1206-jw-392elf/res-3k9-5-0-25w-1206-thick-film/dp/2787808 | 2 | 0.042 | 0.084
koelvin | L: 50mm; W: 50mm; H: 50mm; 4.05K/W | ok | TME | https://www.tme.eu/be/en/details/icks50x50x50/heatsinks-for-led/fischer-elektronik/ | 1 | 12.24 | 12.24
thermische pad | SILICONE, 150X0.5MM | ok | farnell | https://be.farnell.com/multicomp-pro/mpgcs-030-150-0-5a/thermal-pad-silicone-150x0-5mm/dp/3267479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 | 1 | 13.1 | 13.1 | prijs gedeeld./4 | 3.275
PCB | FR-4 print 1.6mm dikte +stencil |  | jlcpcb |  | 1 | 13.27 | 13.27
totaal prijs |  |  |  |  |  |  | 68.7519 |  | 55.5569

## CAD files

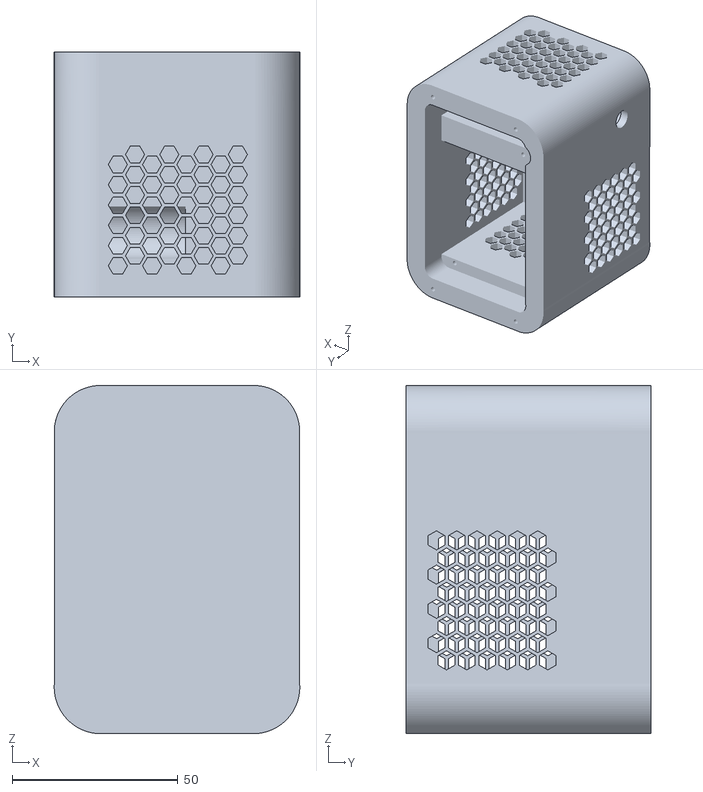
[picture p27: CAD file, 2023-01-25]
3d print/Case_led_driver_-Lukas_Verschraegen (1).stl
74.1 x 74.0 x 105.0

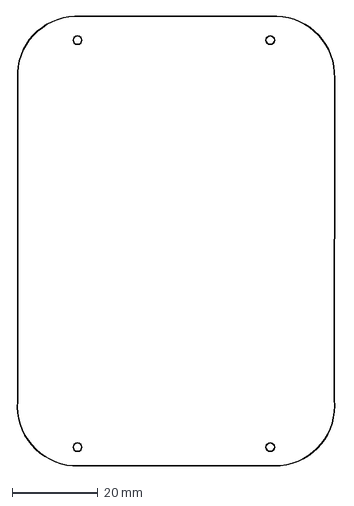
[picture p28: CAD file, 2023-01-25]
lasercutter/laser.dxf
75.0 x 105.0 mm

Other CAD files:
3d print/led driver v14.f3z

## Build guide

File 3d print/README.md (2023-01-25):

Hier vindt je de stl file voor als je direct de print wilt maken.
Als u aanpassingen wilt maken of het ontwerp in detail wilt bekijken, kan u de fusion 360 file gebruiken.

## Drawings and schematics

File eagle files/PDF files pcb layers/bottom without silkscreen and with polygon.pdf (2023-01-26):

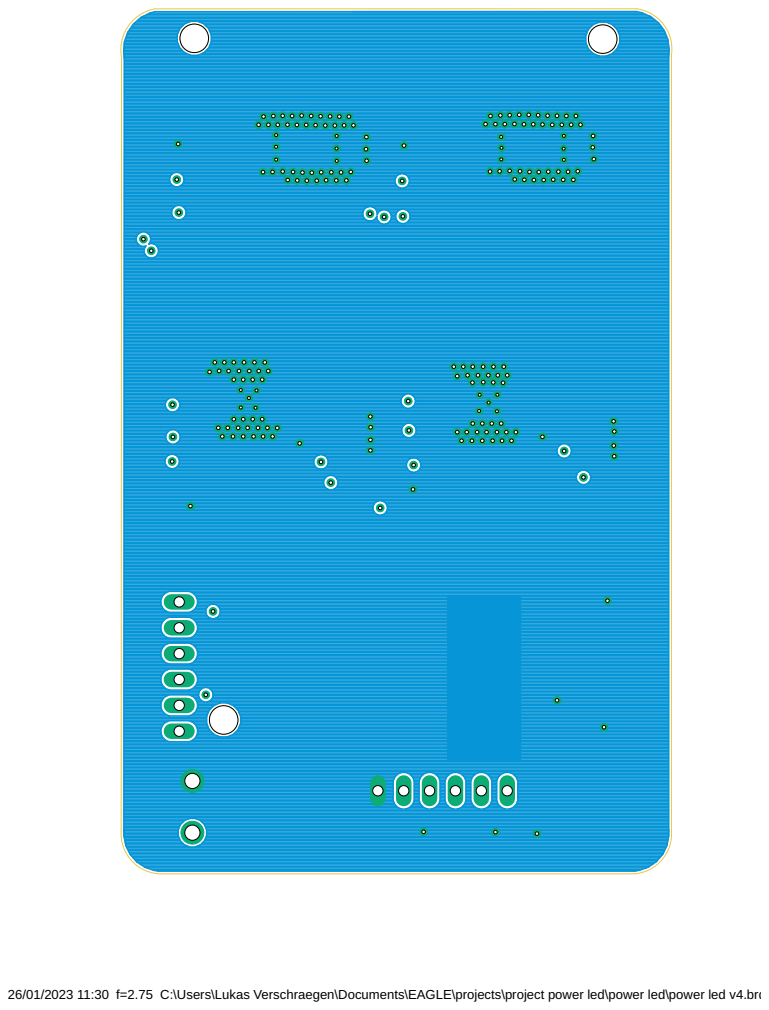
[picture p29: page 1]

26/01/2023 11:30 f=2.75 C:\Users\Lukas Verschraegen\Documents\EAGLE\projects\project power led\power led\power led v4.brd

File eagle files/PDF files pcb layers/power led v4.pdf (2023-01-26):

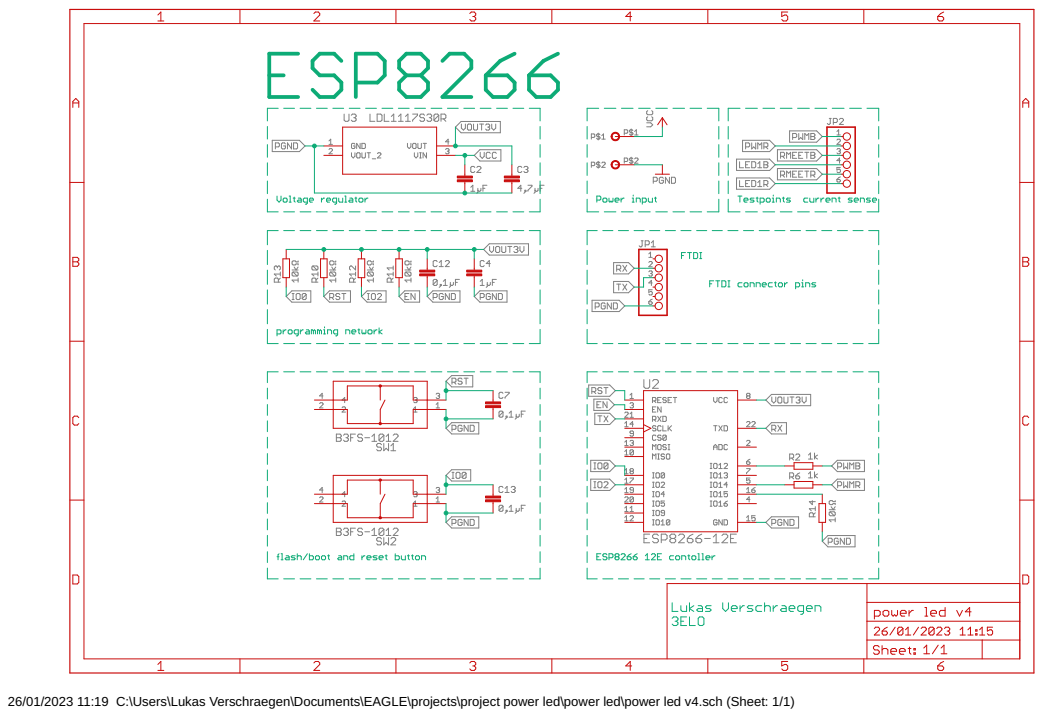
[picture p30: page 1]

26/01/2023 11:19 C:\Users\Lukas Verschraegen\Documents\EAGLE\projects\project power led\power led\power led v4.sch (Sheet: 1/1)

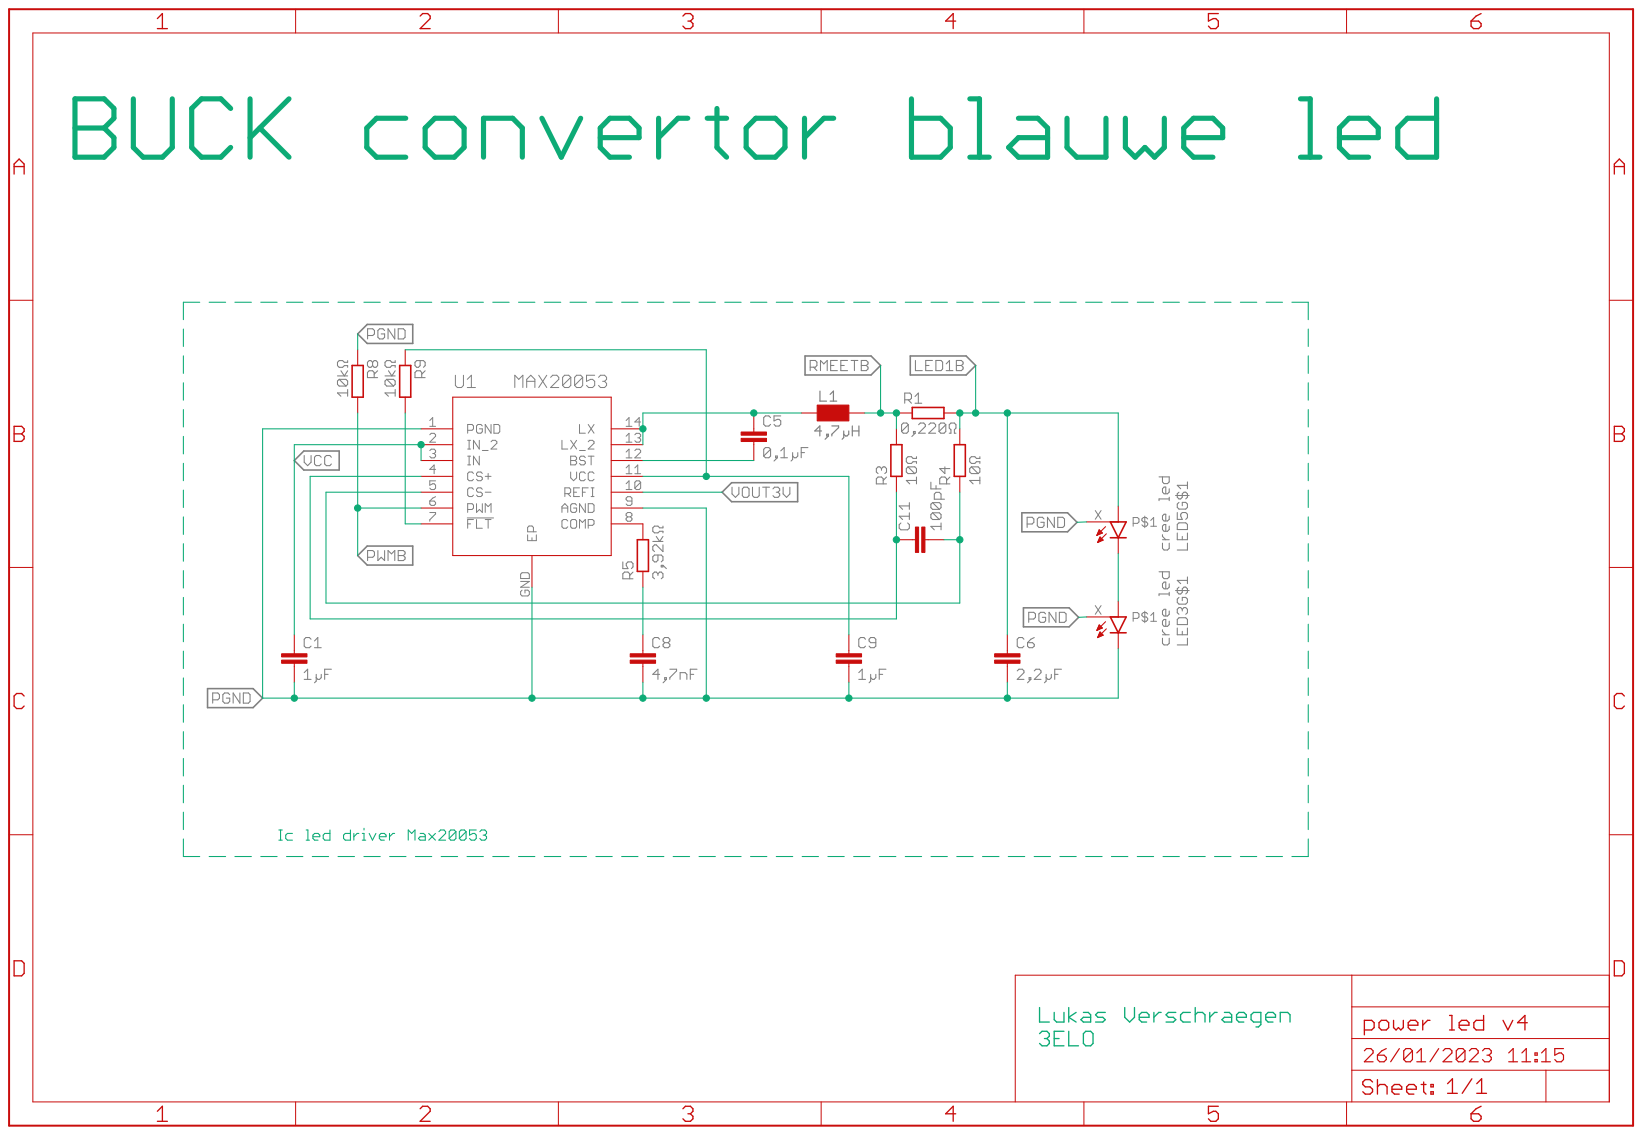
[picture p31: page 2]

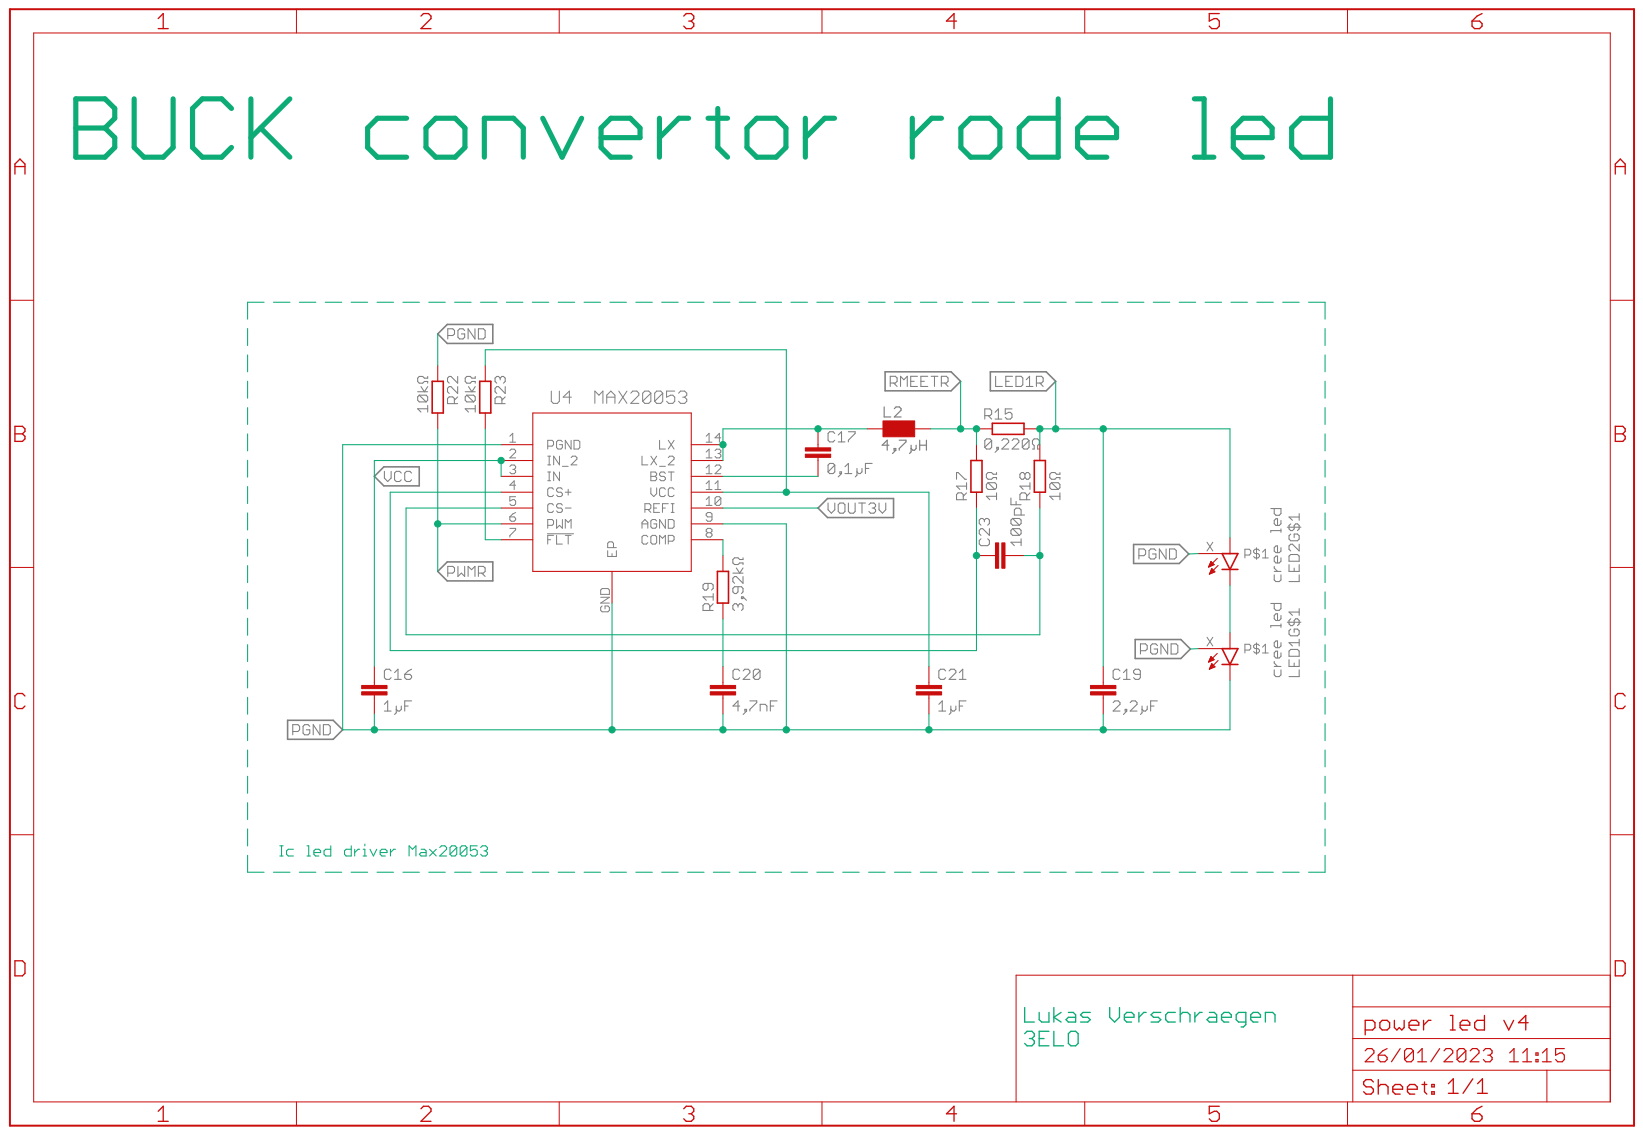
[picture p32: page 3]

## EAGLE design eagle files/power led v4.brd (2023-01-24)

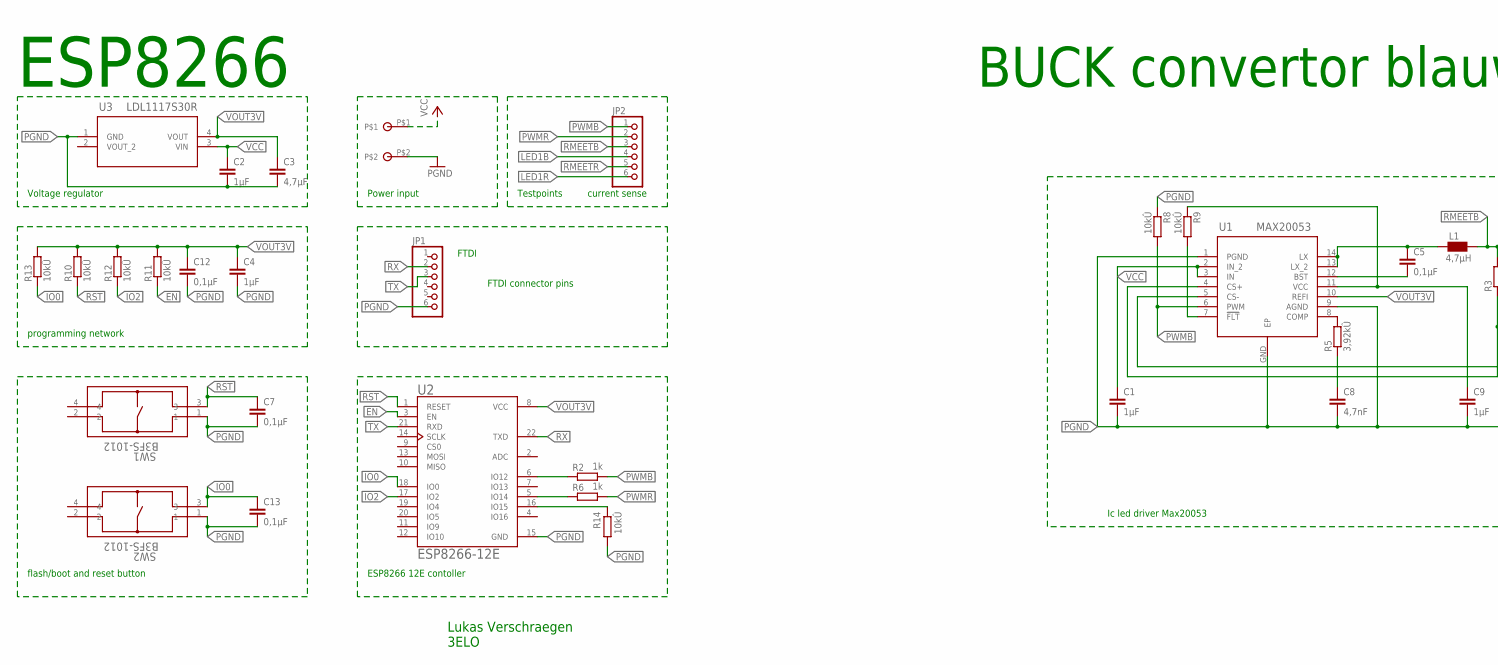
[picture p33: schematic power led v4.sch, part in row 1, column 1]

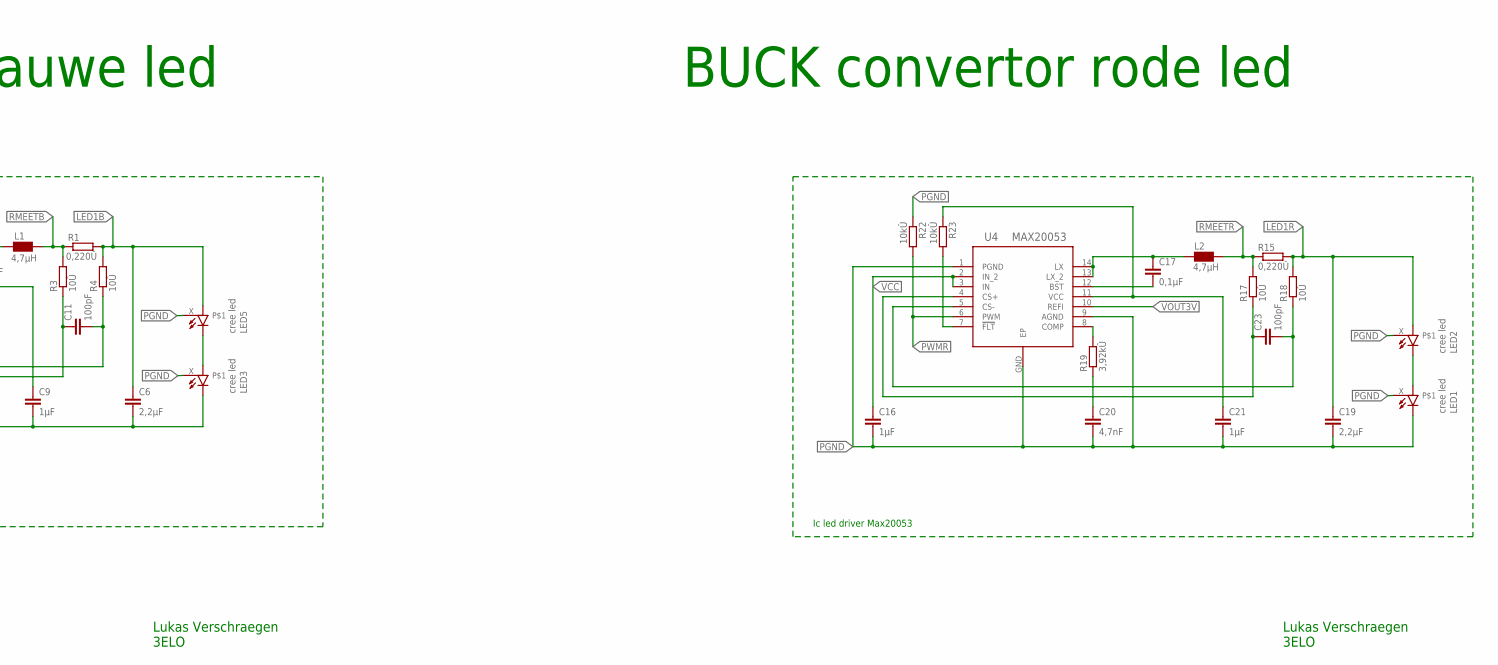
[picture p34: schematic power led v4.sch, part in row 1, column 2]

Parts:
C1, C2, C4, C9, C16, C21: 1µF; C1206
C3: 4,7µF; C1206
C5, C7, C12, C13, C17: 0,1µF; C1206
C6, C19: 2,2µF; C1206
C8, C20: 4,7nF; C1206
C11, C23: 100pF; C1206
JP1, JP2: PINHD-1X6; 1X06
L1, L2: 4,7µH; IND_7447789004_WRE-M
LED1, LED2, LED3, LED5: cree led; CREE_XLAMP
R1, R15: 0,220Û; R1206
R2, R6: 1k; R1206
R3, R4, R17, R18: 10Û; R1206
R5, R19: 3,92kÛ; R1206
R8, R9, R10, R11, R12, R13, R14, R22, R23: 10kÛ; R1206
SW1, SW2: B3FS-1012; SW_B3FS-1010_OMR
U1, U4: MAX20053; 21-0108-E_14L_MXM-M
U2: ESP8266-12E; XCVR_ESP8266-12E/ESP-12E
U3: LDL1117S30R; SOT223_STM
X1: TERMINA5MM; TERMINAL5MM

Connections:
BSTB: C5.2, U1.12 (BST)
BSTR: C17.2, U4.12 (BST)
COMPB: R5.2, U1.8 (COMP)
COMPR: R19.2, U4.8 (COMP)
CS+B: C11.1, R3.1, U1.4 (CS+)
CS+R: C23.1, R17.1, U4.4 (CS+)
CS-B: C11.2, R4.1, U1.5 (CS-)
CS-R: C23.2, R18.1, U4.5 (CS-)
EN: R11.1, U2.3 (EN)
FLTB: R9.2, U1.7 (!FLT)
FLTR: R23.2, U4.7 (!FLT)
IO0: C13.1, R13.1, SW2.3, U2.18 (IO0)
IO2: R12.1, U2.17 (IO2)
IO15: R14.1, U2.16 (IO15)
LED1B: C6.1, JP2.4, LED5.A, LED5.A@1 (A), R1.2, R4.2
LED1R: C19.1, JP2.6, LED2.A, LED2.A@1 (A), R15.2, R18.2
LED2B: LED3.A, LED3.A@1 (A), LED5.C, LED5.C@1 (C)
LED2R1: LED1.A, LED1.A@1 (A), LED2.C, LED2.C@1 (C)
LXB: C5.1, L1.2, U1.13 (LX_2), U1.14 (LX)
LXR: C17.1, L2.2, U4.13 (LX_2), U4.14 (LX)
unnamed: C20.1, R19.1
unnamed: C8.1, R5.1
unnamed: R2.1, U2.6 (IO12)
unnamed: R6.1, U2.5 (IO14)
PGND: C1.2, C2.2, C3.2, C4.2, C6.2, C7.2, C8.2, C9.2, C12.2, C13.2, C16.2, C19.2, C20.2, C21.2, JP1.6, LED1.C, LED1.C@1 (C), LED1.X, LED2.X, LED3.C, LED3.C@1 (C), LED3.X, LED5.X, R8.1, R14.2, R22.1, SW1.1, SW2.1, U1.1 (PGND), U1.9 (AGND), U1.GND (EP), U2.15 (GND), U3.1 (GND), U4.1 (PGND), U4.9 (AGND), U4.GND (EP), X1.P$2
PWMB: JP2.1, R2.2, R8.2, U1.6 (PWM)
PWMR: JP2.2, R6.2, R22.2, U4.6 (PWM)
RMEETB: JP2.3, L1.1, R1.1, R3.2
RMEETR: JP2.5, L2.1, R15.1, R17.2
RST: C7.1, R10.1, SW1.3, U2.1 (RESET)
RX: JP1.2, U2.22 (TXD)
TX: JP1.3, U2.21 (RXD)
VCC: C1.1, C2.1, C16.1, U1.2 (IN_2), U1.3 (IN), U3.3 (VIN), U4.2 (IN_2), U4.3 (IN), X1.P$1
VCCB: C9.1, R9.1, U1.11 (VCC)
VCCR: C21.1, R23.1, U4.11 (VCC)
VOUT3V: C3.1, C4.1, C12.1, R10.2, R11.2, R12.2, R13.2, U1.10 (REFI), U2.8 (VCC), U3.4 (VOUT), U4.10 (REFI)

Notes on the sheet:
Lukas Verschraegen 3ELO
ESP8266
BUCK convertor blauwe led
FTDI
Ic led driver Max20053
BUCK convertor rode led
Voltage regulator
programming network
flash/boot and reset button
FTDI connector pins
ESP8266 12E contoller
Power input
Testpoints
current sense

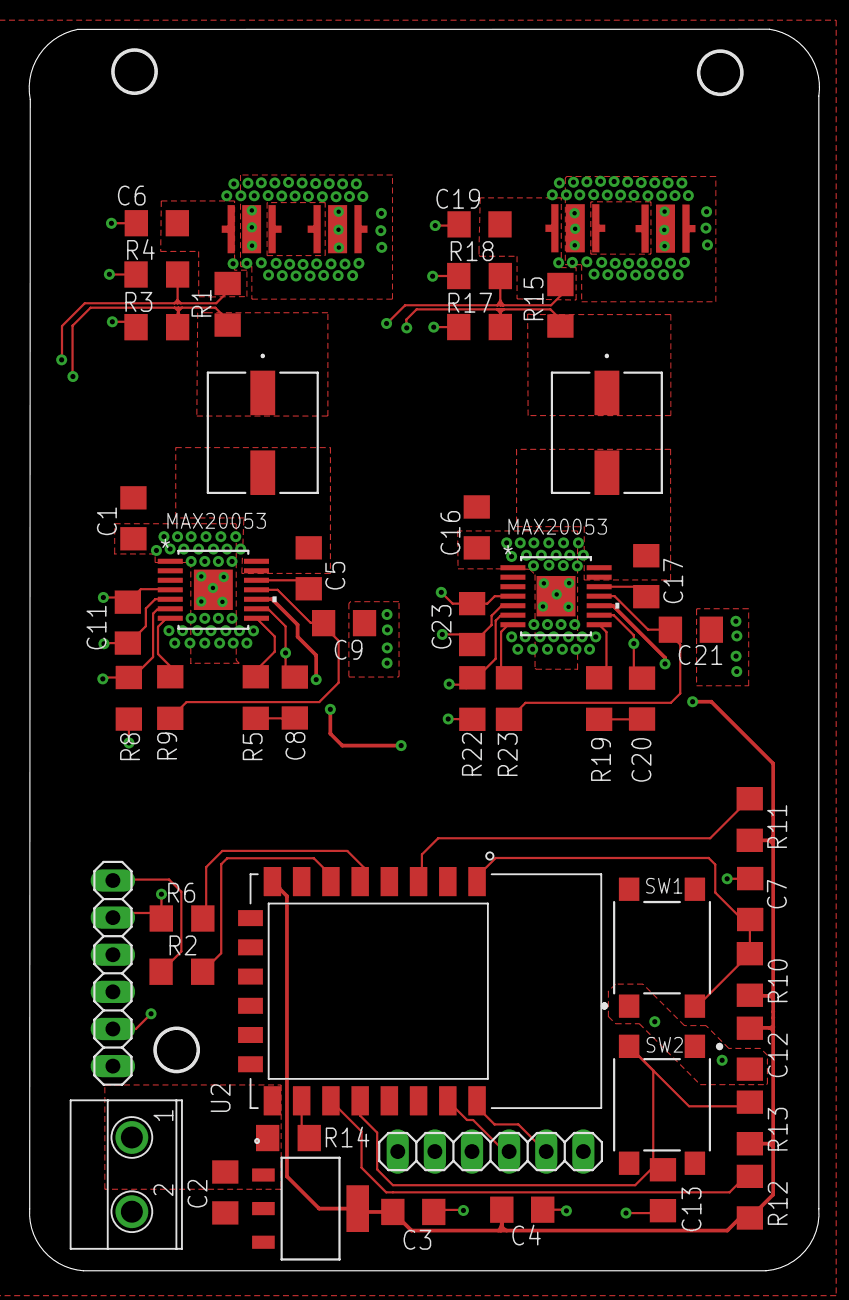
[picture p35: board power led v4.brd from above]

Board: 4 copper layers, 54.1 x 85.0 mm, 55 parts (0 on the bottom side), 36 nets.

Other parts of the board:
U$1, U$2, U$3: 2,8

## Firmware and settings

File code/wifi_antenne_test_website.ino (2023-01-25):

/*********
  credits:
  Rui Santos
  Complete project details at https://randomnerdtutorials.com
*********/

// Load Wi-Fi library
#include <ESP8266WiFi.h>

// Replace with your network credentials
const char* ssid     = "Galaxy A409A16";
const char* password = "ecab6165";


// Set web server port number to 80
WiFiServer server(80);

// Variable to store the HTTP request
String header;

// Auxiliar variables to store the current output state
int pwm_signaal = 0;


int led_pinR = 14;
int led_pinB = 12;

// Current time
unsigned long currentTime = millis();
// Previous time
unsigned long previousTime = 0;
// Define timeout time in milliseconds (example: 2000ms = 2s)
const long timeoutTime = 2000;

void setup() {
  Serial.begin(115200);
  // Initialize the output variables as outputs
  pinMode(led_pinR, OUTPUT);
  pinMode(led_pinB, OUTPUT);
  // Connect to Wi-Fi network with SSID and password
  Serial.print("Connecting to ");
  Serial.println(ssid);
  WiFi.begin(ssid, password);
  while (WiFi.status() != WL_CONNECTED) {
    delay(500);
    Serial.print(".");
  }
  // Print local IP address and start web server
  Serial.println("");
  Serial.println("WiFi connected.");
  Serial.println("IP address: ");
  Serial.println(WiFi.localIP());
  server.begin();
}

void loop() {
  for (int i = 0; i <= pwm_signaal; i = i + 3) {
    analogWrite(led_pinR, i);  // fade in first LED
    analogWrite(led_pinB, pwm_signaal - i); // fade out second LED
    delay(1);
  }
  for (int i = pwm_signaal; i >= 0; i = i - 3) {
    analogWrite(led_pinR, i);  // fade out first LED
    analogWrite(led_pinB, pwm_signaal - i); // fade in second LED
    delay(1);
  }
  WiFiClient client = server.available();   // Listen for incoming clients

  if (client) {                             // If a new client connects,
    Serial.println("New Client.");          // print a message out in the serial port
    String currentLine = "";                // make a String to hold incoming data from the client
    currentTime = millis();
    previousTime = currentTime;
    while (client.connected() && currentTime - previousTime <= timeoutTime) { // loop while the client's connected
      currentTime = millis();
      if (client.available()) {             // if there's bytes to read from the client,
        char c = client.read();             // read a byte, then
        Serial.write(c);                    // print it out the serial monitor
        header += c;
        if (c == '\n') {                    // if the byte is a newline character
          // if the current line is blank, you got two newline characters in a row.
          // that's the end of the client HTTP request, so send a response:
          if (currentLine.length() == 0) {
            // HTTP headers always start with a response code (e.g. HTTP/1.1 200 OK)
            // and a content-type so the client knows what's coming, then a blank line:
            client.println("HTTP/1.1 200 OK");
            client.println("Content-type:text/html");
            client.println("Connection: close");
            client.println();

            // turns the GPIOs on and off
            if (header.indexOf("GET /pwm+/on") >= 0) {
              Serial.println("led sneller");
              if (pwm_signaal >= 1020) {
                pwm_signaal = 1020;
              }
              else {
                pwm_signaal = pwm_signaal + 255;
              }
              Serial.println(pwm_signaal);
              //digitalWrite(output5, HIGH);
            }  else if (header.indexOf("GET /pwm-/on") >= 0) {
              Serial.println("led trager");
              if (pwm_signaal <= 0) {
                pwm_signaal = 0;
              }
              else {
                pwm_signaal = pwm_signaal - 255;
              }
              Serial.println(pwm_signaal);
              //digitalWrite(output4, HIGH);
            }
            // Display the HTML web page
            client.println("<!DOCTYPE html><html>");
            client.println("<head><meta name=\"viewport\" content=\"width=device-width, initial-scale=1\">");
            client.println("<link rel=\"icon\" href=\"data:,\">");
            // CSS to style the on/off buttons
            // Feel free to change the background-color and font-size attributes to fit your preferences
            client.println("<style>html { font-family: Helvetica; display: inline-block; margin: 0px auto; text-align: center;}");
            client.println(".button { background-color: #195B6A; border: none; color: white; padding: 16px 40px;");
            client.println("text-decoration: none; font-size: 30px; margin: 2px; cursor: pointer;}");
            client.println(".button2 {background-color: #77878A;}</style></head>");

            // Web Page Heading
            client.println("<body><h1>ESP8266 Web Server</h1>");

            // Display current state, and ON/OFF buttons for GPIO 5
            client.println("<p>led seller " + String(pwm_signaal) + "</p>");

            client.println("<p><a href=\"/pwm+/on\"><button class=\"button\">+</button></a></p>");


            // Display current state, and ON/OFF buttons for GPIO 4
            client.println("<p>led dimmen " + String(pwm_signaal) + "</p>");
            // If the output4State is off, it displays the ON button

            client.println("<p><a href=\"/pwm-/on\"><button class=\"button\">-</button></a></p>");

            client.println("</body></html>");

            // The HTTP response ends with another blank line
            client.println();
            // Break out of the while loop
            break;
          } else { // if you got a newline, then clear currentLine
            currentLine = "";
          }
        } else if (c != '\r') {  // if you got anything else but a carriage return character,
          currentLine += c;      // add it to the end of the currentLine
        }

      }
    }
    // Clear the header variable
    header = "";
    // Close the connection
    client.stop();
    Serial.println("Client disconnected.");
    Serial.println("");
  }
}

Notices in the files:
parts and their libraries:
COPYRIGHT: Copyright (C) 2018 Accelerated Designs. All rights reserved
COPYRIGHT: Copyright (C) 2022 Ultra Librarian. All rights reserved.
